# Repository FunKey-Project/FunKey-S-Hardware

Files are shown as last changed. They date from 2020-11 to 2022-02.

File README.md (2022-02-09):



## FunKey S Hardware
This repository contains all the hardware design and production files required to build the [FunKey-S retro-gaming console](https://www.funkey-project.com/) electronic PCBA using the [KiCAD ECAD tools](https://kicad.org/).

If you don't want to install these tools but still want to get an idea of what it looks like, you can check the [schematics](https://github.com/FunKey-Project/FunKey-S-Hardware/blob/master/PDF/FunKey%20Schematics.pdf) and the [layout](https://github.com/FunKey-Project/FunKey-S-Hardware/blob/master/PDF/FunKey%20PCB.pdf) in PDF format, the interactive [BOM](https://github.com/FunKey-Project/FunKey-S-Hardware/tree/master/BOM) is directly in HTML format, you can download it and display it in a browser.

The FunKey S is a small foldable retro-gaming console.

Its electronic parts consist in:
 - 1x main PCB (0.8 mm thickness) with components on both sides, the maximum component height above PCB on both sides is 1.5 mm. Current revision for this board is Revision E
 - 1x 1.54” IPS LCD TFT screen with SPI interface and using a custom flex cable
 - 1x 420 mAh 402540 LiPo battery

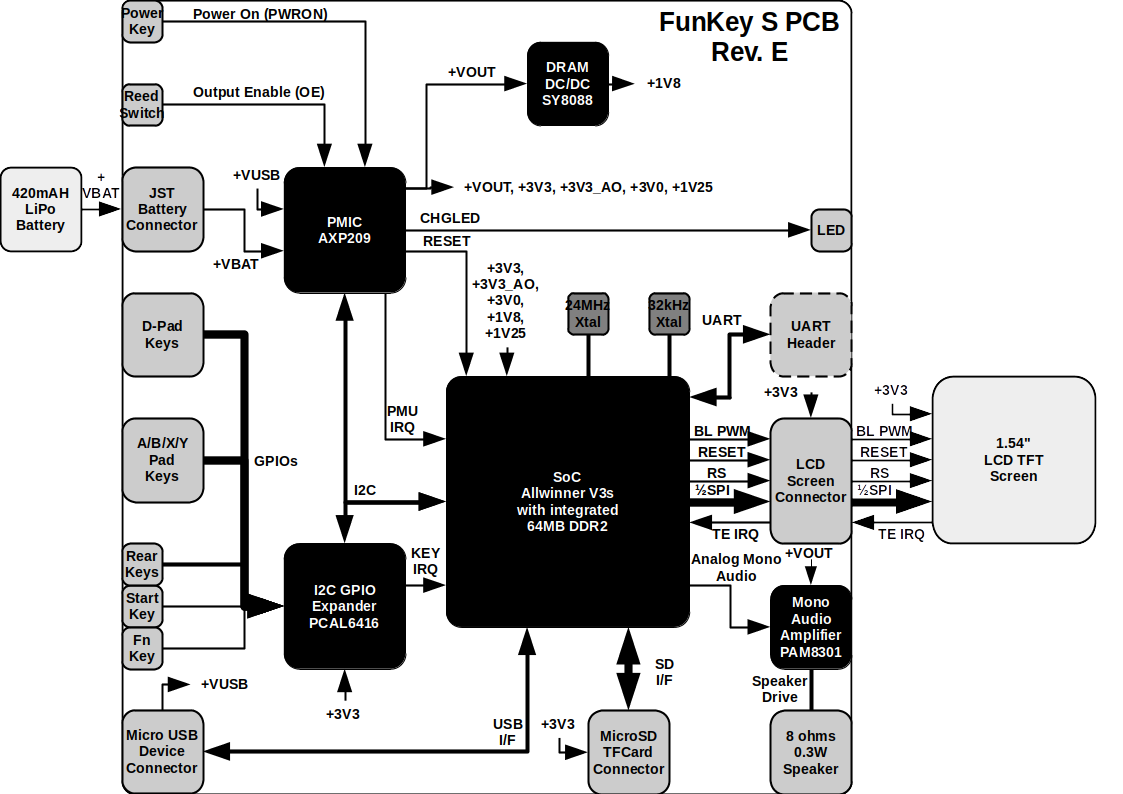
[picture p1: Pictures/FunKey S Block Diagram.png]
FunKey S Block Diagram


The FunKey S PCBA Rev. E contains the following main components:
 - 1x Allwinner V3s SoC with integrated 64MB DDR2 DRAM (LQFP128 package)
 - 1x X-Powers AXP209 companion PMIC chip to provide almost all required power supply rails (QFN48 package)
 - 1x Sylergy SY8088 Buck DC/DC SMPS chip to provide the DRAM power supply rail (SOT23-5 package)
 - 1x NXP PCAL6416 I2C GPIO expander to control all buttons and keypads (except Power Key) (QFN24 package)
 - 1x Diodes Inc. PAM8301 mono audio amplifier (TSOT26 package)
 - 1x 24 MHz main crystal
 - 1x 32.768 kHz RTC crystal
 - 1x Standex-Meder MK24 Reed switch for magnet proximity detection
 - 1x LED for charge indication
 - 1x 8 Ω 0.3 W built-in speaker
 - 1x Micro USB edge-mounted connector
 - 1x Micro SD (TF Card) Push/Push low-profile connector
 - 1x Hirose DF37 0.4 mm pitch miniature LCD connector
 - 1x JST 1 mm pitch battery connector
 - 1x 1.27 mm pitch debug UART header (not mounted)

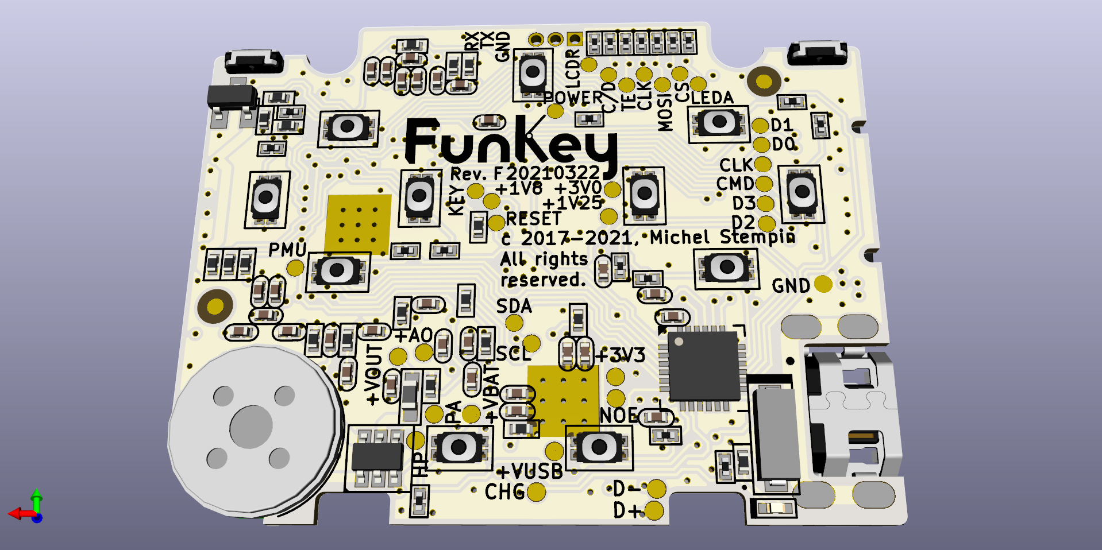
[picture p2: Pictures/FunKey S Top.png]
FunKey Top


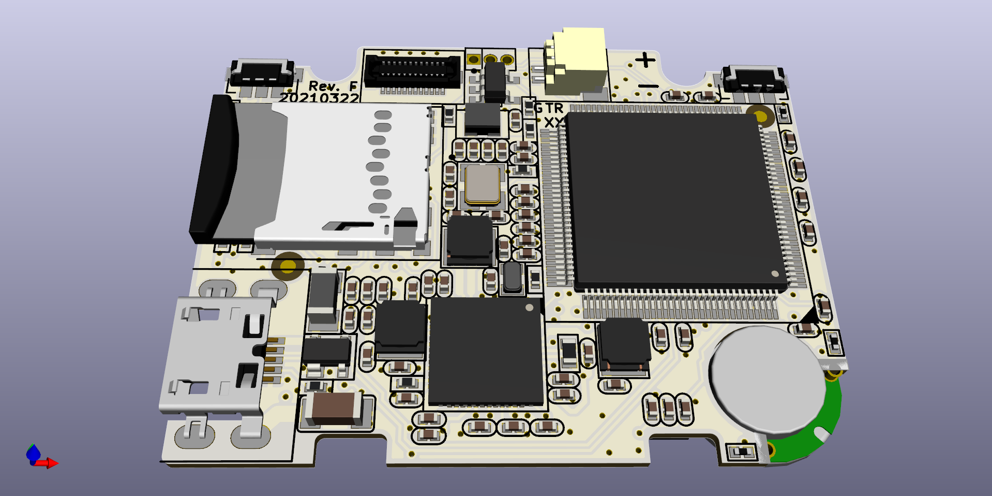
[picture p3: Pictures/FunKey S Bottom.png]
FunKey Bottom


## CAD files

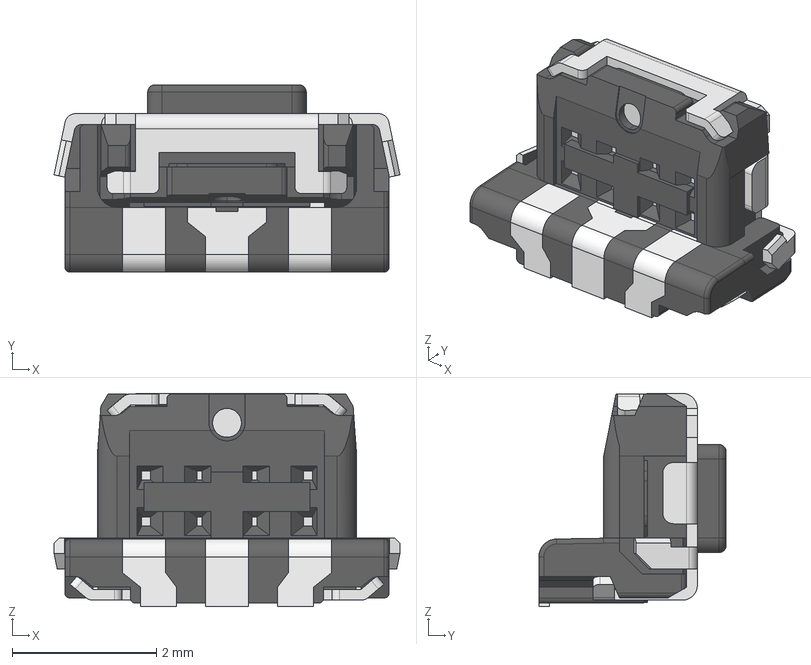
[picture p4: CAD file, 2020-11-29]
shapes3D/EVPAEBB2A.step
4.80 x 2.60 x 2.96 mm
EVPAEBB2A
EVPAEBB2A001
EVPAEBB2A002
EVPAEBB2A003
EVPAEBB2A004
EVPAEBB2A005
EVPAEBB2A006
EVPAEBB2A007
EVPAEBB2A008
EVPAEBB2A009
EVPAEBB2A010
EVPAEBB2A011
EVPAEBB2A012
EVPAEBB2A013

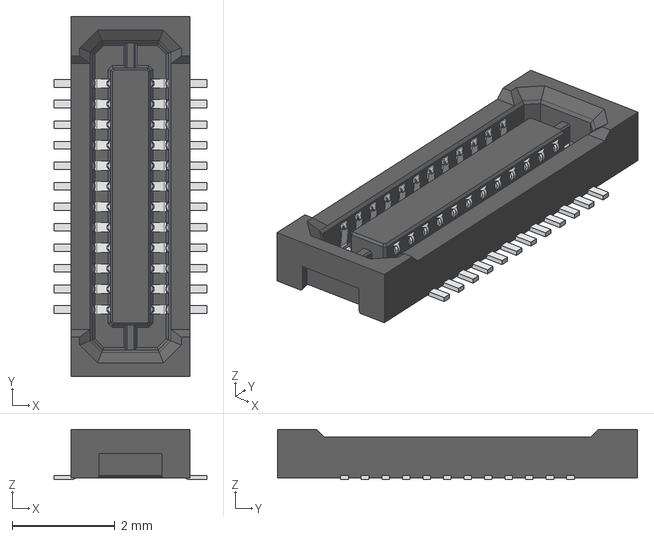
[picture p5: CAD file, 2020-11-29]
shapes3D/HIROSE_DF37NC-24DS-0.4V.step
2.98 x 7.02 x 0.98 mm

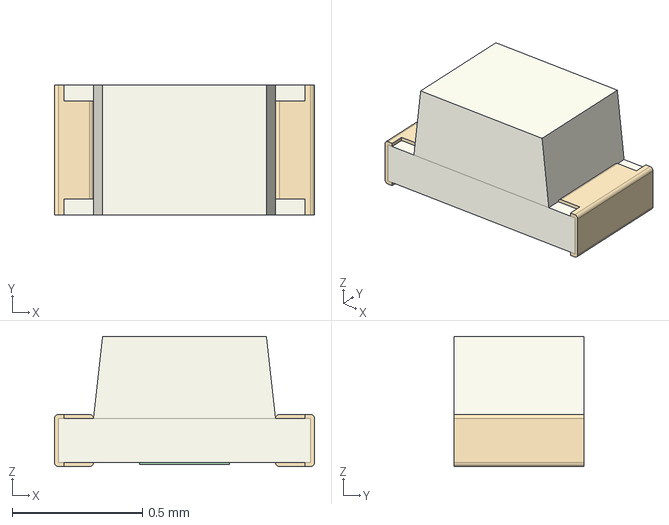
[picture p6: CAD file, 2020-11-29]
shapes3D/LED_0402_1005Metric.step
1.00 x 0.5 x 0.5 mm

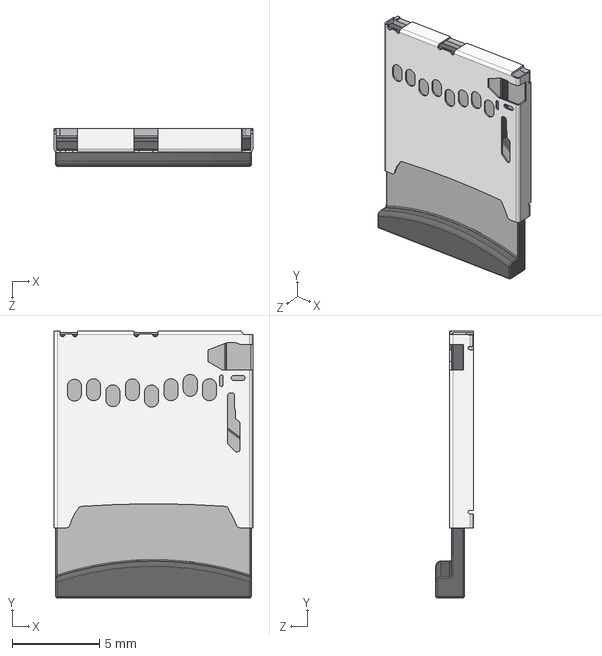
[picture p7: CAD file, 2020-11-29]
shapes3D/TF-110_with_Micro-SD.step
11.3 x 15.3 x 2.15 mm
CONNECTOR MICRO SD TF-110
MicroSD

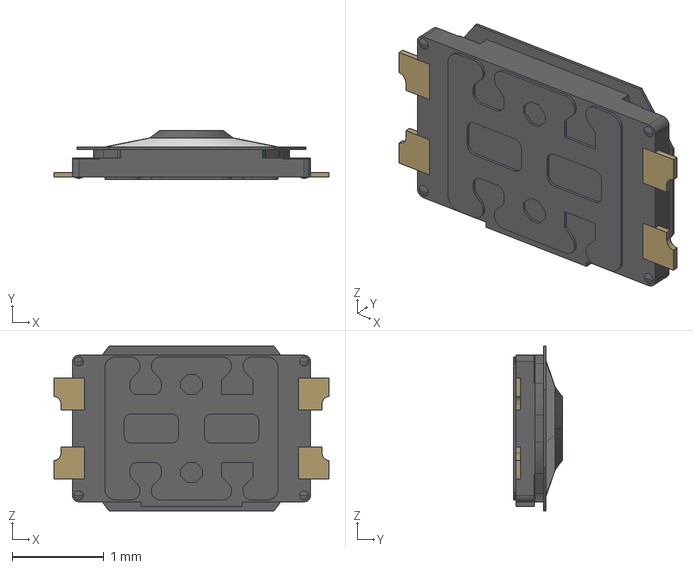
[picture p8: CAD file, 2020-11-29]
shapes3D/PANASONIC_EVPBB2A9B000.step
3.00 x 0.53 x 1.80 mm

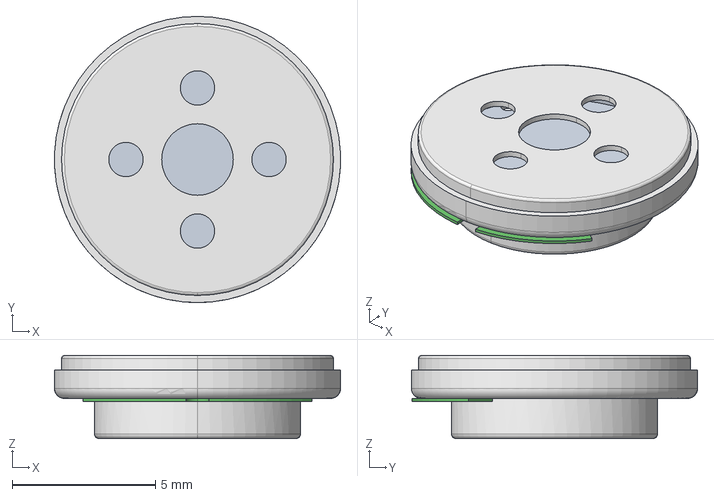
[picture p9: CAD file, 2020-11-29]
shapes3D/CUI_CDM-10008.step
9.99 x 10.0 x 2.90 mm

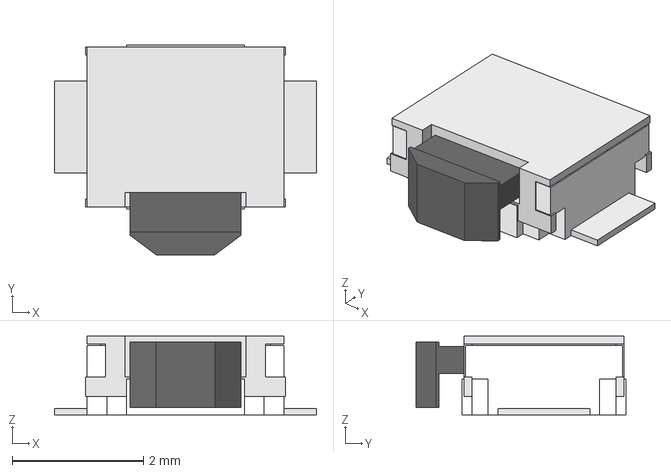
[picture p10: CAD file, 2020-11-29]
shapes3D/OMRON_B3U-3000P.step
4.00 x 3.20 x 1.20 mm

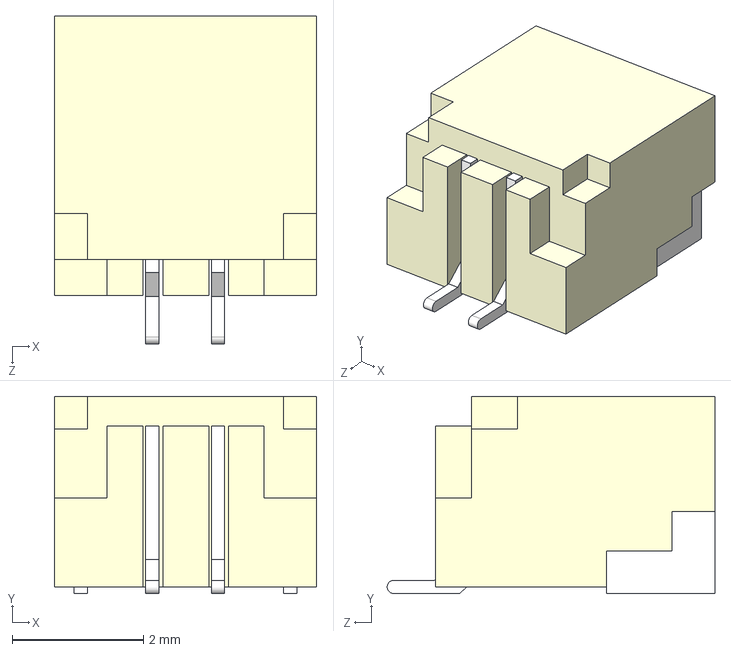
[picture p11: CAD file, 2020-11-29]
shapes3D/JST_SM02B-SRSS-TB.step
3.99 x 3.00 x 4.99 mm

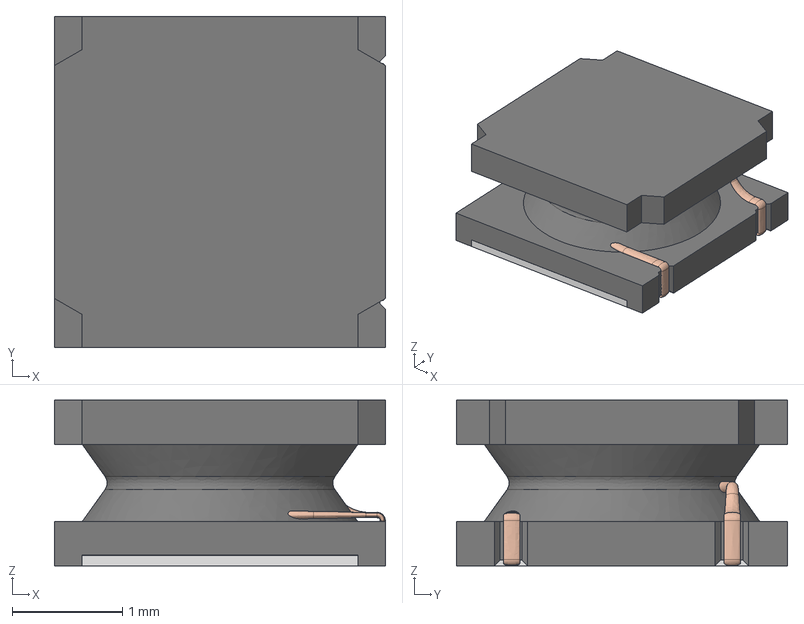
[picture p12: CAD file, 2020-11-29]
shapes3D/WE-LQS-3015.step
3.00 x 3.00 x 1.50 mm

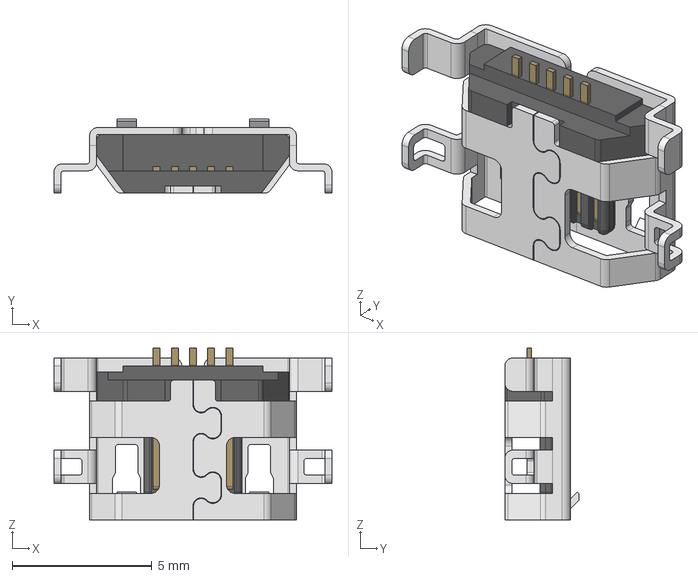
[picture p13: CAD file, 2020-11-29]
shapes3D/U02-BFD3111B0-009.step
9.95 x 2.66 x 6.15 mm

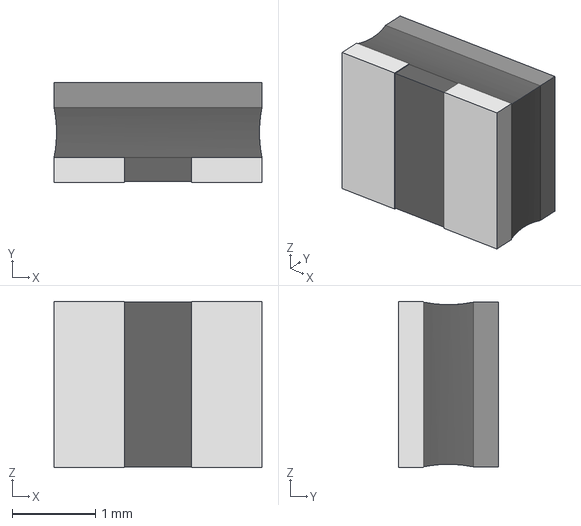
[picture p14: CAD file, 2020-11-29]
shapes3D/L1008.step
2.50 x 1.20 x 2.00 mm

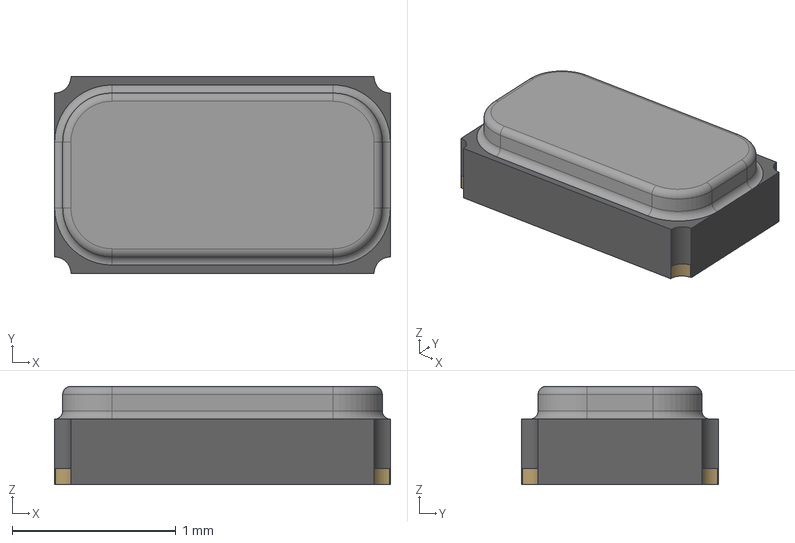
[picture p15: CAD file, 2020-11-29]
shapes3D/FC-12M.step
2.05 x 1.20 x 0.6 mm

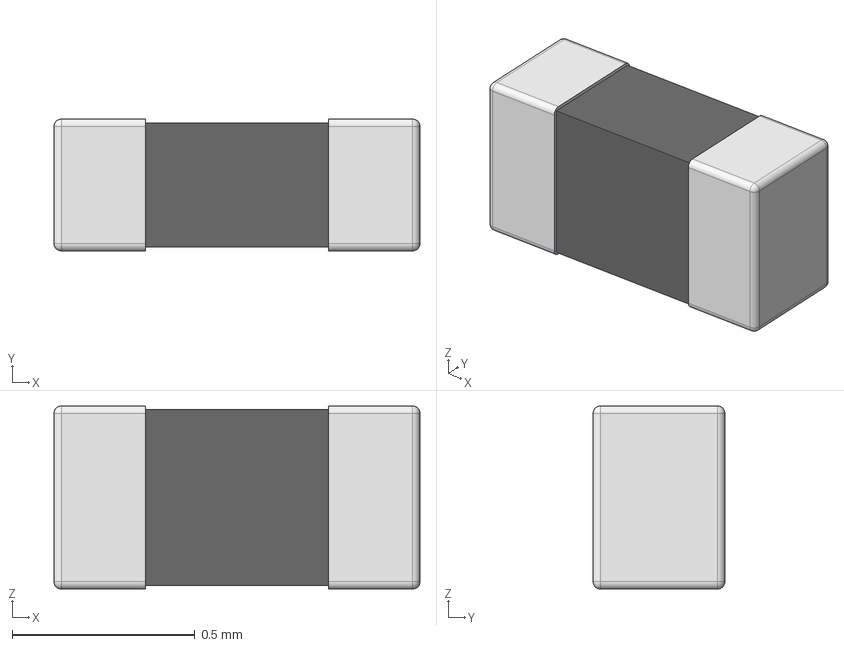
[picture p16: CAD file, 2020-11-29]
shapes3D/CG0402MLC.step
1.00 x 0.36 x 0.5 mm

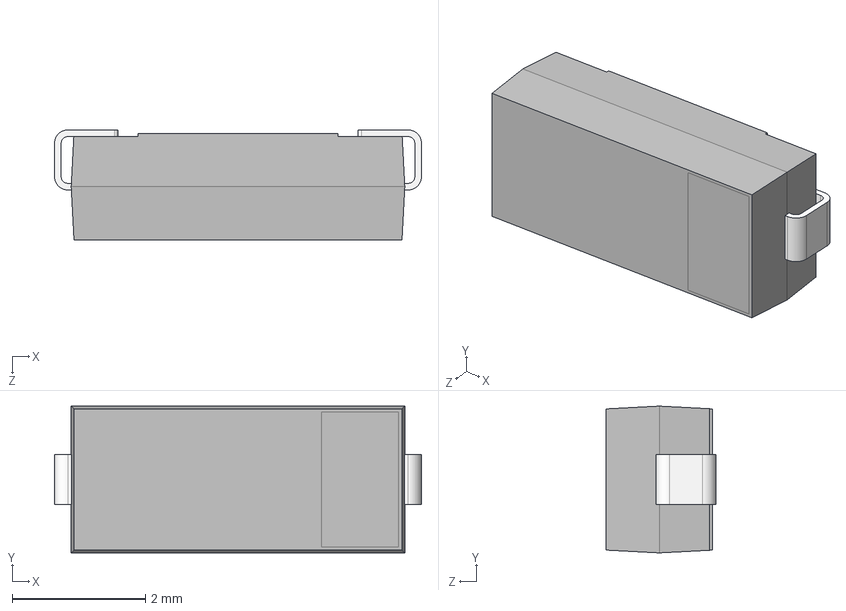
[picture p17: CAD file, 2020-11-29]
shapes3D/MEDER_MK24-A-3.step
5.50 x 2.20 x 1.65 mm

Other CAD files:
shapes3D/CRYSTAL-3225.step

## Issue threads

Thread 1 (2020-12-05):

What LCD is this? and the Driver Chip?

Helder1981, 2020-12-05:
This looks like a custom made LCD or a standard LCD with custom Flex on it. Can you tell us what the original LCD was or the driver IC it uses so other LCDs can be used.

Thanks.

Michel-FK, 2021-02-20:
The original screen we used is a SAEF SF-TC154B-8377A-N which used to be available on Alibaba, but this is no longer the case.

You can find its datasheet attached.

It uses an ST7789V integrated driver IC.

[ALIBABA_SAEF_SF-TC154B-8377A-N_annote.pdf](https://github.com/FunKey-Project/FunKey-S-Hardware/files/6016271/ALIBABA_SAEF_SF-TC154B-8377A-N_annote.pdf)

Our current screen is no longer manufactured by SAEF, but our changes to the orignal model are:

- change the flex shape and dimensions
- add the TE (Tearing Effect) signal from the driver IC on the connector (pin 9)

Here is our current screen specs:
https://github.com/FunKey-Project/FunKey-S-Hardware/blob/master/Datasheets/DISPLAY%20-%20SF-TC154B-8737A-N%20-%20CUSTOM%20FLEX%20-%200.3.PDF

Closed 2021-02-20.

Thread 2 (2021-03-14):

PMIC default voltages

wolfallein, 2021-03-14:
Hi,

very nice project and very well documented! Congrats!

I have a question regarding the default voltage on the AXP209. I was reading the datasheet but it is not very clear how the voltage is set when the system starts, before u-boot, or kernel takes control.

For the LDO1, and DC3 there are some set pins that in the funkey schematic sets them to 3.3V.
The Vdram is fixed to 1.8V.

LDO2 can vary from 1.8V-3.3V, but in the schematic it is 3.0V.
DC3 can vary from 0.7-3.5V, but in the schematic it is 1.25V (Vcore).

So, how the voltage is set before the CPU wakes?

BR

Michel-FK, 2021-03-15:
Hi,

Just a small precision: Vcore is DC2, not DC3.

Yes, the AXP209 datasheet is not clear at all regarding the default voltages, and has some [other mistakes](http://www.chip-community.org/index.php/AXP209) too.

In the [Allwinner V3s reference design](https://github.com/Squonk42/V3s_Documentation/blob/master/V3S_CDR_STD_V1_0_20150514.pdf), the AXP203 is used with the following configuration

- LDO1: 3.3V Always On (RTC/GSensor)
- LDO2 : 3.0V(AVcc/pll)
- LDO3: 0.7~3.V (Camera AVDD)
- LDO4: 1.25~3.3V (Camera DVDD)
- DC2: 1.25V (CPU/SYS/EPHY)
- DC3: 3.3V (USB/NOR/TF/FLASH/LED/VCC-IO/LCD)

As X-Powers is an Allwinner sister company specialized in power chips for the Allwinner SoC, they are tailor-made for these chips, and as the AXP209 was sold on Aliexpress as a bundle with the V3s, we figured out that it would default to the right settings regarding the adjustable output voltages.

It is indeed the case, and as in the reference design, the default voltages for LDO2 is 3.0V, and DC2 is 1.25V, despite the lack of information in the datasheet (default values are XXXX!).

So, there is no software adjustment required at all during the whole boot process.

Upon startup, the voltages are thus:

- LDO1: 3.3V Always On 30mA (Vcc_rtc)
- LDO2 : 3.0V 200mA (AVCC/Vcc_pll)
- LDO3: N/U
- LDO4: N/U
- DC2: 1.25V 1.6A (Vcpu/Vsys/Vdd_phy)
- DC3: 3.3V 1.2A (Vcc_io/Vcc_ephy/Vcc_mcsi/Vusb/Vcc_io)
- External SY8088AAC DC/DC for 1.8V 1.0A (Vdram)

wolfallein, 2021-03-15:
Thanks a lot for the information.

This was driving me crazy. I also found small mistakes everywhere in their datasheets, seems like they never got a final version.

They always say:
`
"As for more details, please refer to “Default Configuration Instruction".
`

But this section simply doesn't exist.

I was particularly worried about the default voltages because XX means that it can be any value, and this is definitely not good for power regulators that drive SOC's.

I found some differences in their chips, they are not 100% pin-compatible:

* AXP203 -> PIN 27=LDO1SET, PIN15=LX3, PIN16=PGND3
* AXP202 -> PIN 27=PWREN, PIN15=LX3, PIN16=PGND3
* AXP209 -> PIN 27=LDO1SET, PIN15=PGND3, PIN16=LX3

Maybe there are little differences in their registers (like max voltages, timing...), but I didn't check.

I could only see the bundle with the AXP203 at Aliexpress now, so something to consider when buying it ...

Just some little notes regarding the schematic:

1. I noticed there is missing a diode for protection in parallel with the battery connector. I guess you assumed the battery already has such protection, but this is not always the case. If the user replaces the battery with another model that doesn't have the protection and connects with inverted polarity, it can be dangerous, and a single diode could help to increase safety.

2. I see the reed switch is connected to N_OE pin, and from what I could see, it is a power cut. A hardware power cut could generate some corrupted data if the system is mounted as r/w. Since the OS is very limited the chances are low, but maybe you get a bad write in 1/100 (just guessing), maybe with a few of them the system won't be able to boot properly. The axp20x series has a very good mainline kernel support and the power button can send a soft power off or sleep input to the system. The GPIO pins can also behave as input to the system, but I couldn't find that N_OE can be input, although it can be configured to change IRQ state. Maybe I'm missing something, but wouldn't be better to connect the reed switch to PWRON, or one of the GPIO's to get a soft power off instead of using N_OE?

Again, I wanted to thank you for all the information and the detailed documentation of the system, very good work here!

In almost all DIY boards in the market, they claim open source, open hardware but you never get everything they promise.

All the best

Closed 2021-03-15.

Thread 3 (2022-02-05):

hiya -  is this project actually open source?

ladyada, 2022-02-05:
hi there, on the kickstarter page and hackaday page (https://hackaday.io/project/164934/logs) describing this product is the text

"Since its [origins](https://www.funkey-project.com/), the FunKey S has proudly been Open Hardware & Open Source."

with the open source hardware logo and OSI logo:

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

which is awesome! the open source hardware association, whose 'gear' logo is used on that page
https://www.oshwa.org/open-source-hardware-logo/
says
"This logo may be used if your hardware complies with the [Open Source Hardware Definition](https://www.oshwa.org/definition/)."
The definition at https://www.oshwa.org/definition/ specifies that you cannot have 'non commercial' as a restriction on the license.

This repository has a "Non Commercial" license tag.
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

please clarify:

- if this is open hardware and if so, please update the license so it matches the requirements of using the open hardware logo and description.
- or if it not open hardware, you cannot use the logo and must update the hackaday, kickstarter page, etc.

thank you :)

ladyada, 2022-02-09:
hiya @squonk42 @Michel-FK @Vincent-FK please look at this issue and reply!

ladyada, 2022-02-09:
also found on the wiki, another place that is not correct:

https://wiki.funkey-project.com/wiki/FunKey_Wiki_Knowledge_Center#What_is_the_FunKey_S?

```
Where can I find FunKey S device schematics and 3D files?

The FunKey Team has FunKey S schematics, STL files, and a project STEP file for the device's shell components available on [Grabcad](https://grabcad.com/library/funkey-s-1). Schematics for the device's electrical components are available on the FunKey Team's [GitHub page](https://github.com/FunKey-Project/FunKey-S-Hardware). As the device's hardware is open source, users are free to download, modify, and redistribute the listed files.
```

Vincent-FK, 2022-02-09:
Hi @ladyada,

Since it's our first product I must admit we're still tiptoeing around all the legal details so thanks a lot for your input, it's been corrected.

Oh and btw, it goes without saying but still: thanks for Adafruit! Without it Keymu would never have been prototyped, which by extension means the FunKey S would not be there either.

ladyada, 2022-02-09:
thats wonderful - thank you so much for updating the license. im really enjoying my funkey now EVEN MORE SO! :)

Closed 2022-02-09.

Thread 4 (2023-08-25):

Design issues with axp209 schematic

FantasyGmm, 2023-08-25:
The chip documentation states that the 23 Pin BIAS should be connected to a 200K 1% resistor, but in the schematic diagram, the R22 200K 1% resistor is connected to the 21 Pin APS pin,Is this a schematic error or a document error? In the AXP203 design, they all connected the 23 Pin BIAS series resistor to GND instead of grounding the 1uF capacitor

Closed 2023-08-26.

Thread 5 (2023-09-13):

Did you ever consider a hackable retro portable audio player / mp3 player (fork)?

sandreas, 2023-09-13:
Hey there,

I stumbled over this project and open hardware design while searching for a small handheld audio player that is NOT Android based (best case: hackable) and small enough to carry around. Basically, I'm still using my iPods (more specific: iPod Nano 7g with touch screen), because I did not find any alternative that can both play most modern codecs while also having good battery life yet.

So since you share ALL of your designs and hard work publicly, did you ever think of creating such a small audio player?

I think that you already got the most of the work done with the `Funkey S`... the only things I would consider is a non-foldable design with touchscreen and audio jack supporting [TRRS with OMTP](https://en.wikipedia.org/wiki/Phone_connector_(audio)#TRRS) for headphone remote controls (vol+, vol-, play/pause toggle).

If you wanna go all in, you could add some audiophile stuff like 4.4mm BAL 260mW @32-ohm output or Bluetooth 5 LDAC, AptX HD, SBC, AAC licensing - maybe even USB DAC Support

For the first prototype I would like to suggest a device similar to the [Fiio M6](https://www.fiio.com/m6), which is no longer available but was pretty successful. I own one of these and hardware wise it is by far the best audio player I ever had - only problem is the Software. Android 7 which is slow, long boot times and outdated app support.

A dedicated fast audio player with an app also supporting audio books would make a great buy in my opinion...

What do you think?

Closed 2025-02-08.

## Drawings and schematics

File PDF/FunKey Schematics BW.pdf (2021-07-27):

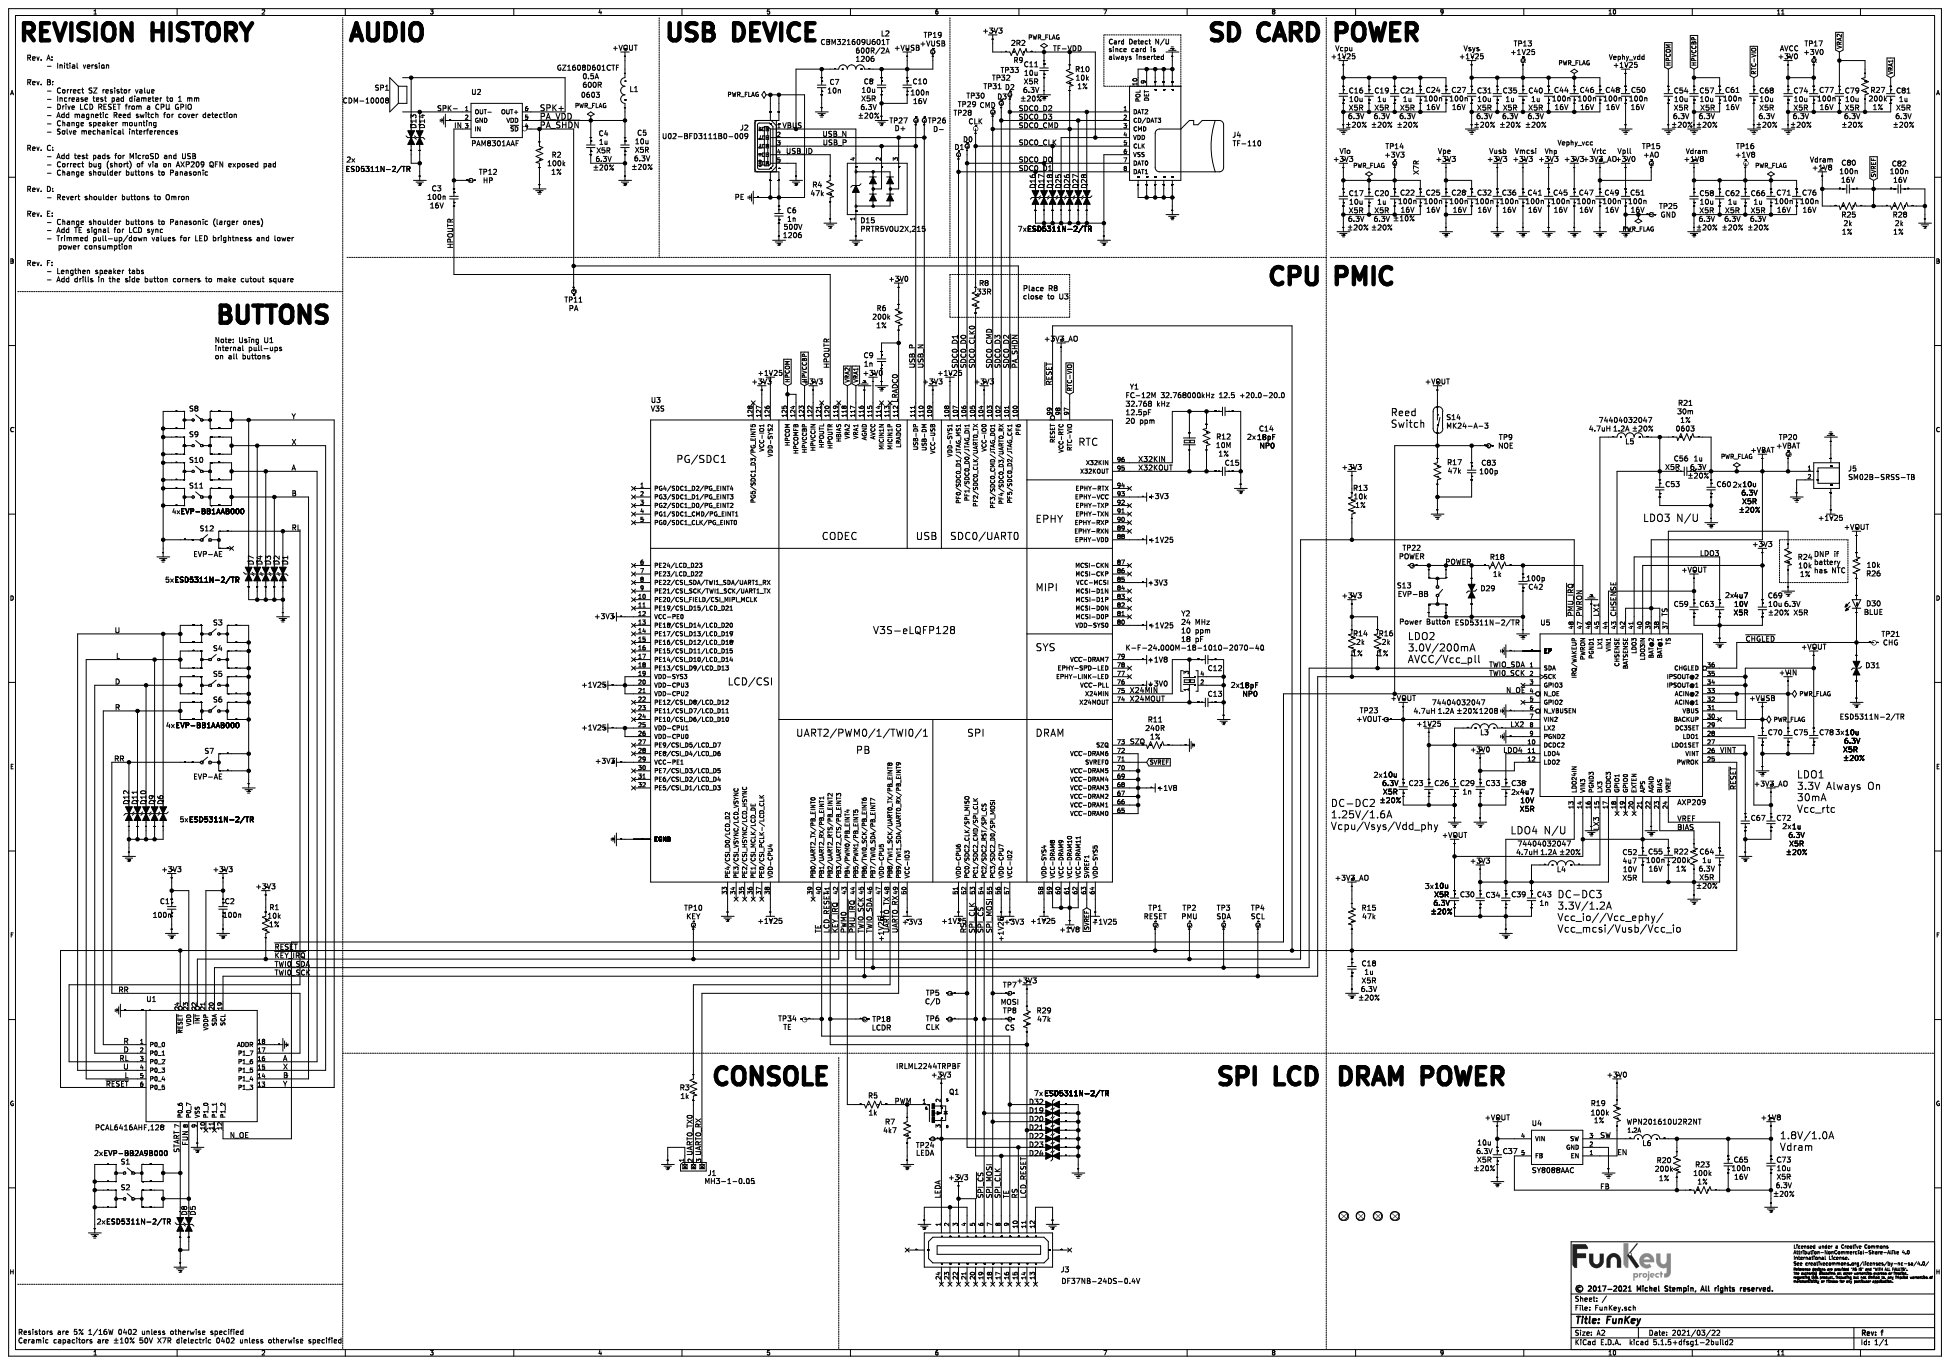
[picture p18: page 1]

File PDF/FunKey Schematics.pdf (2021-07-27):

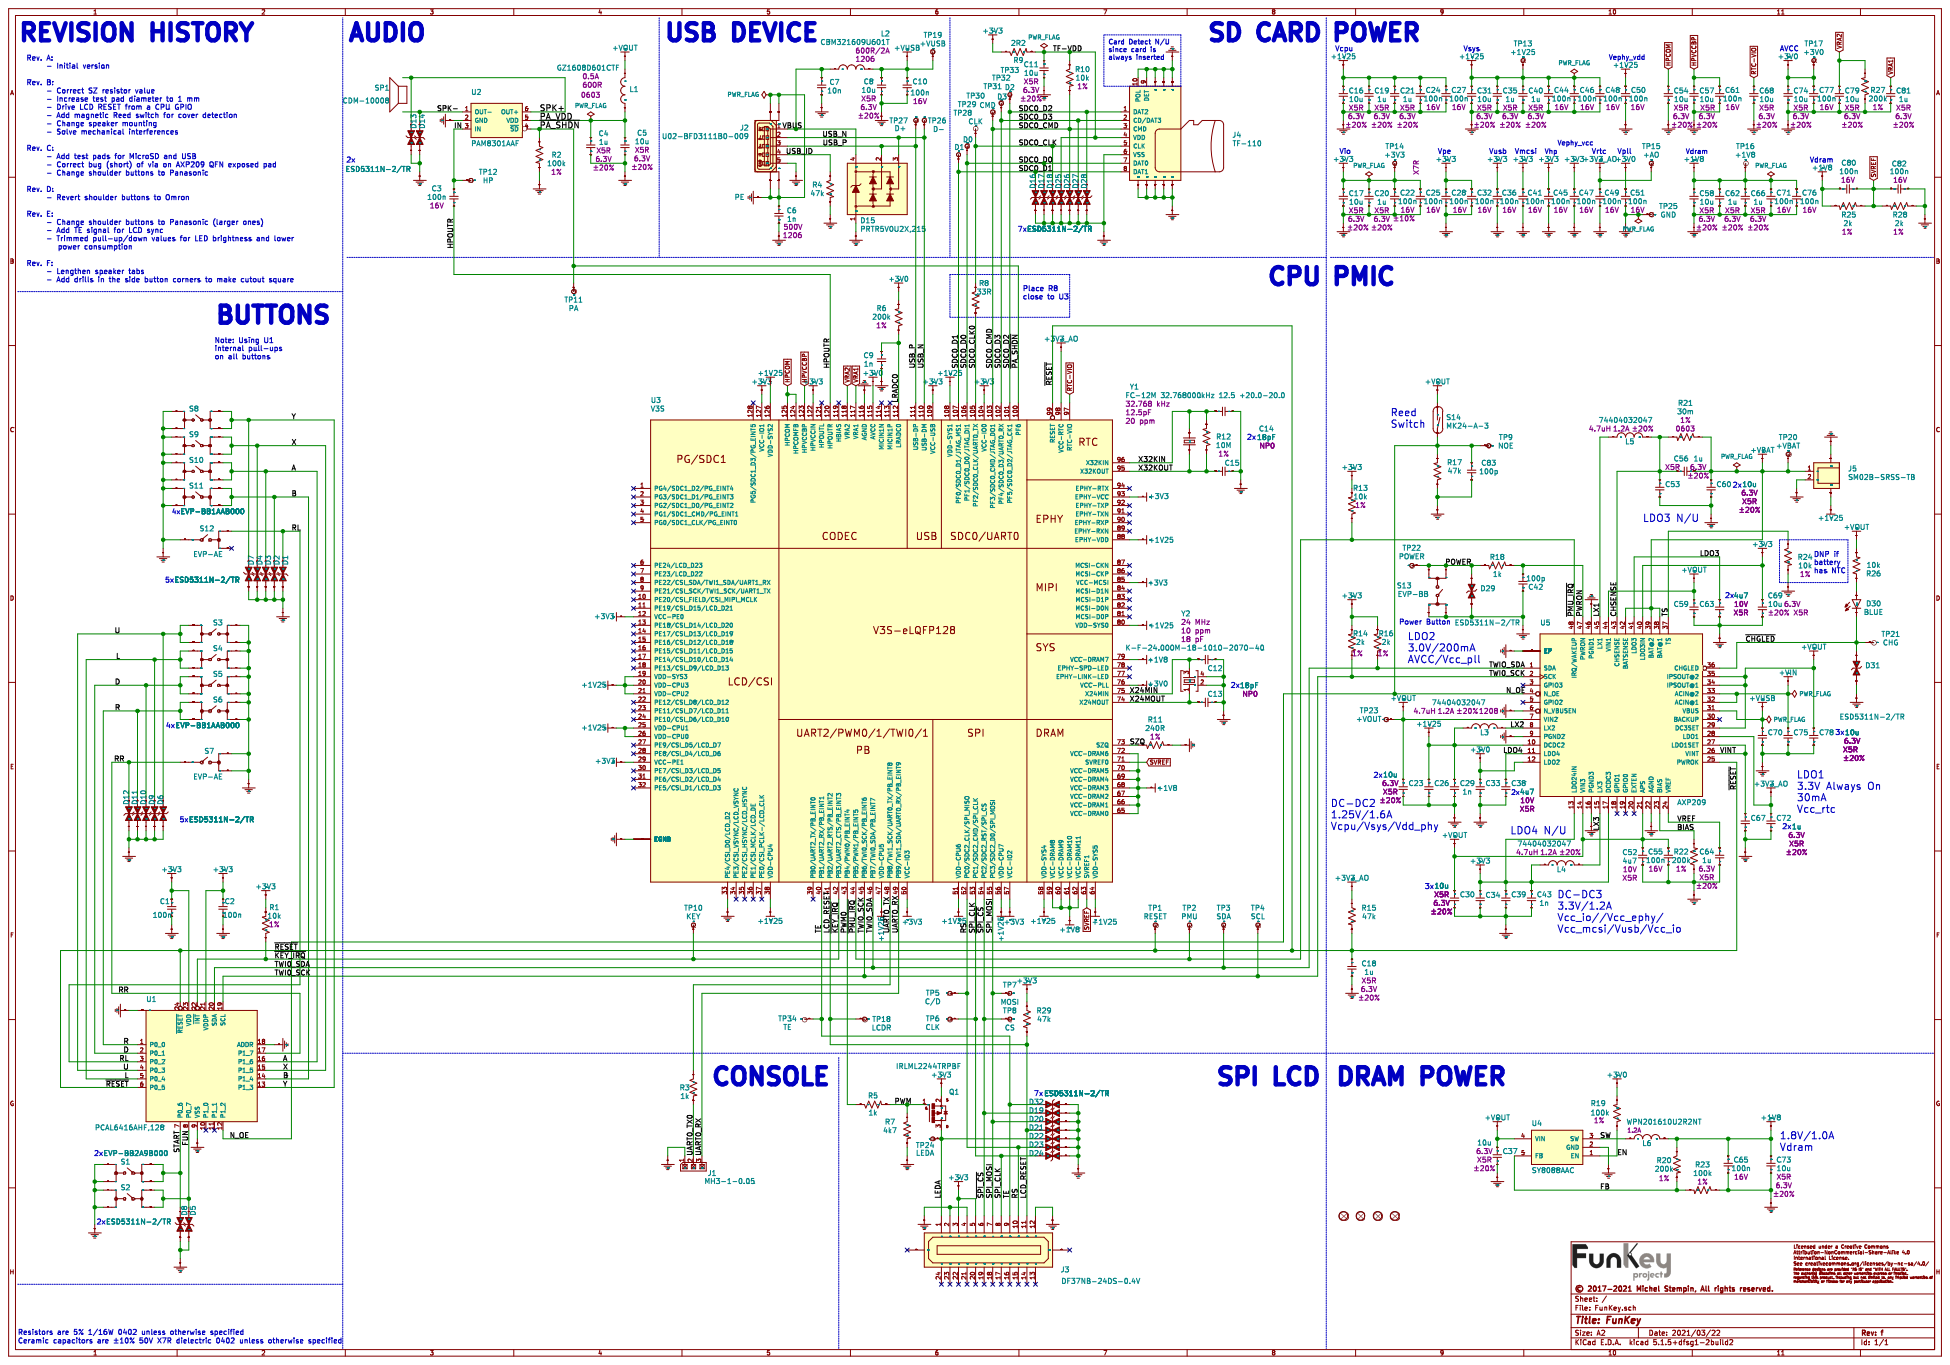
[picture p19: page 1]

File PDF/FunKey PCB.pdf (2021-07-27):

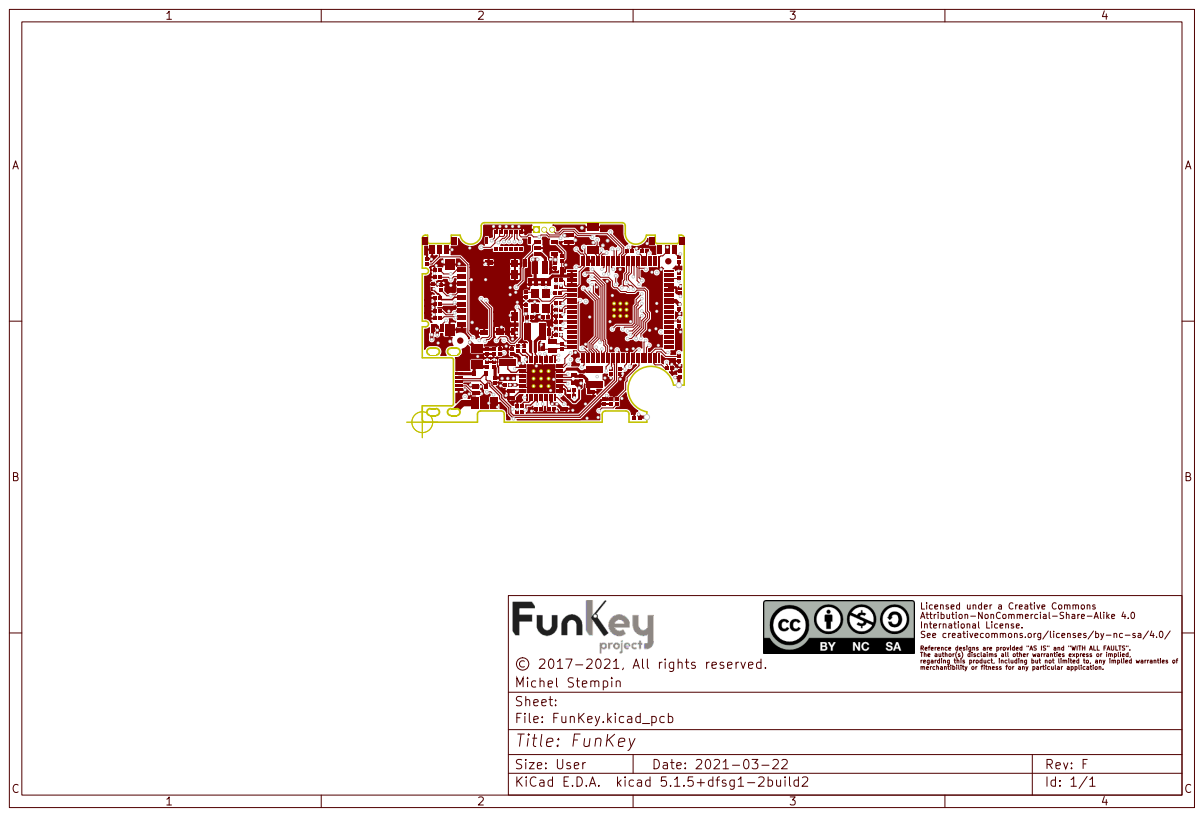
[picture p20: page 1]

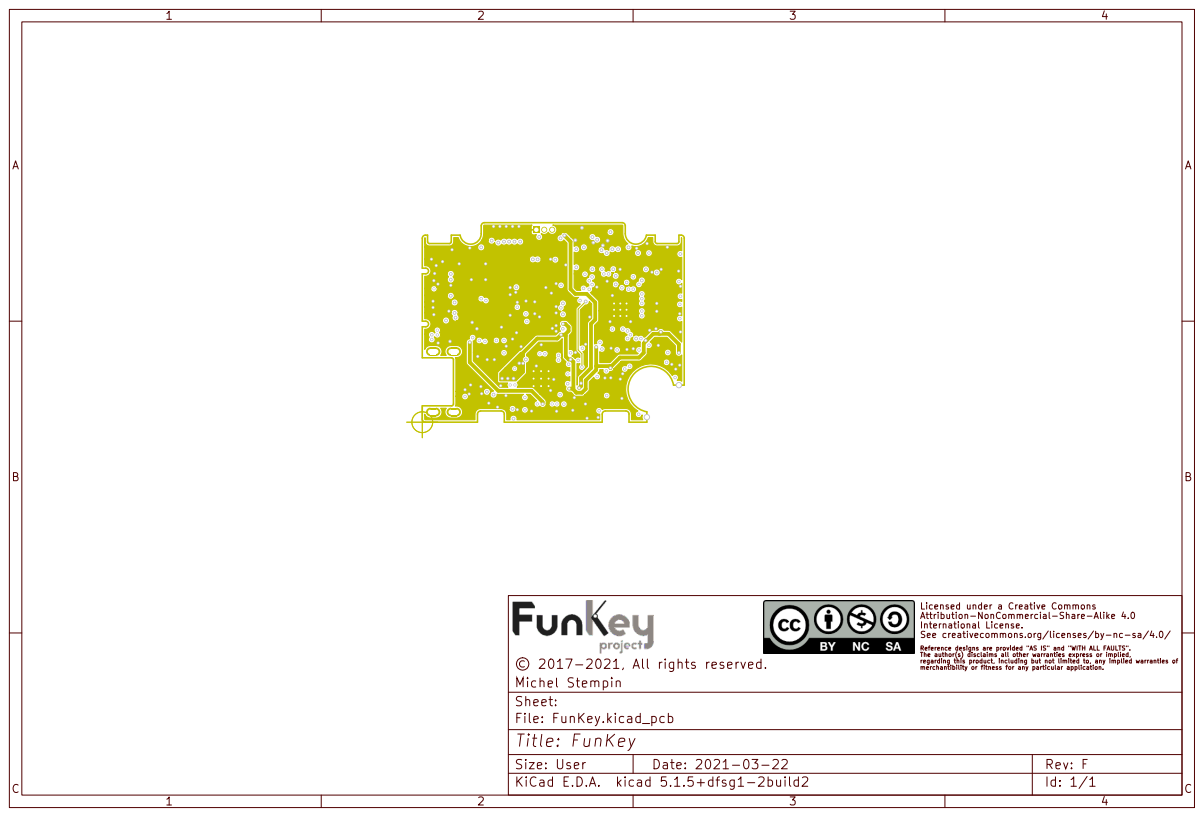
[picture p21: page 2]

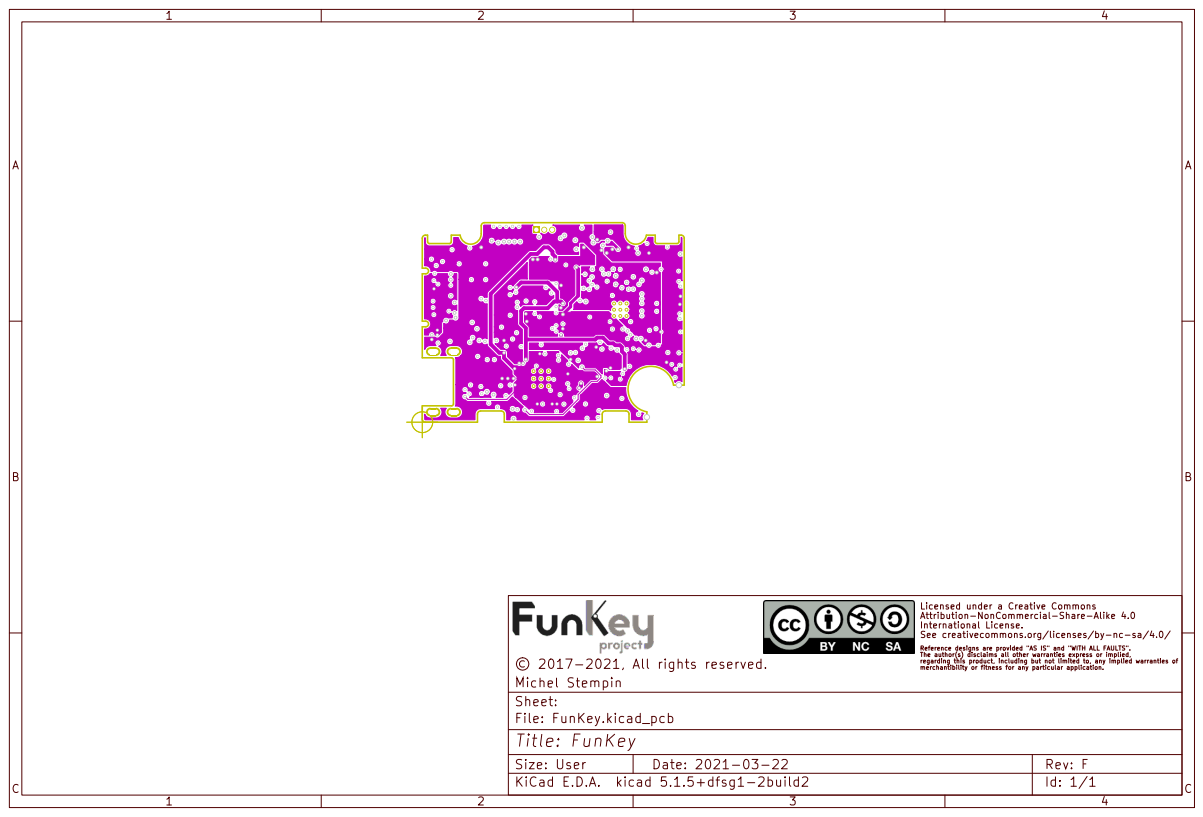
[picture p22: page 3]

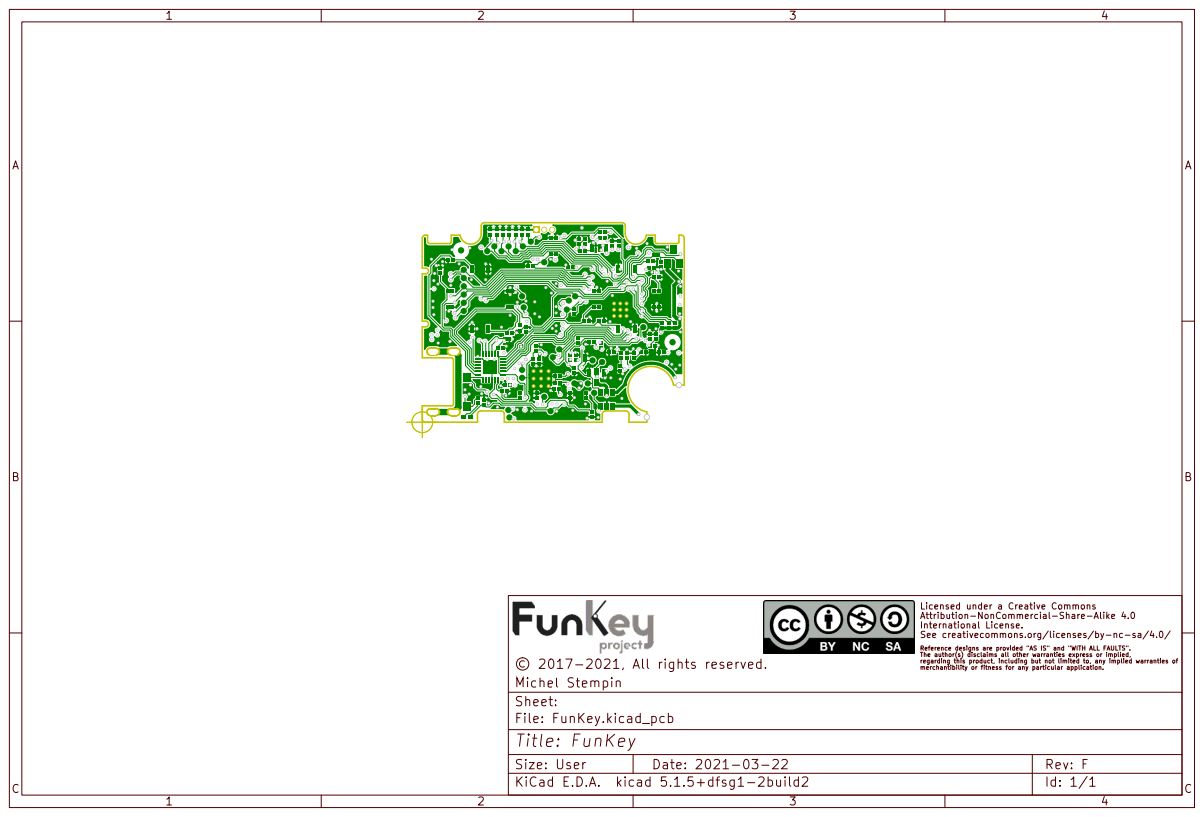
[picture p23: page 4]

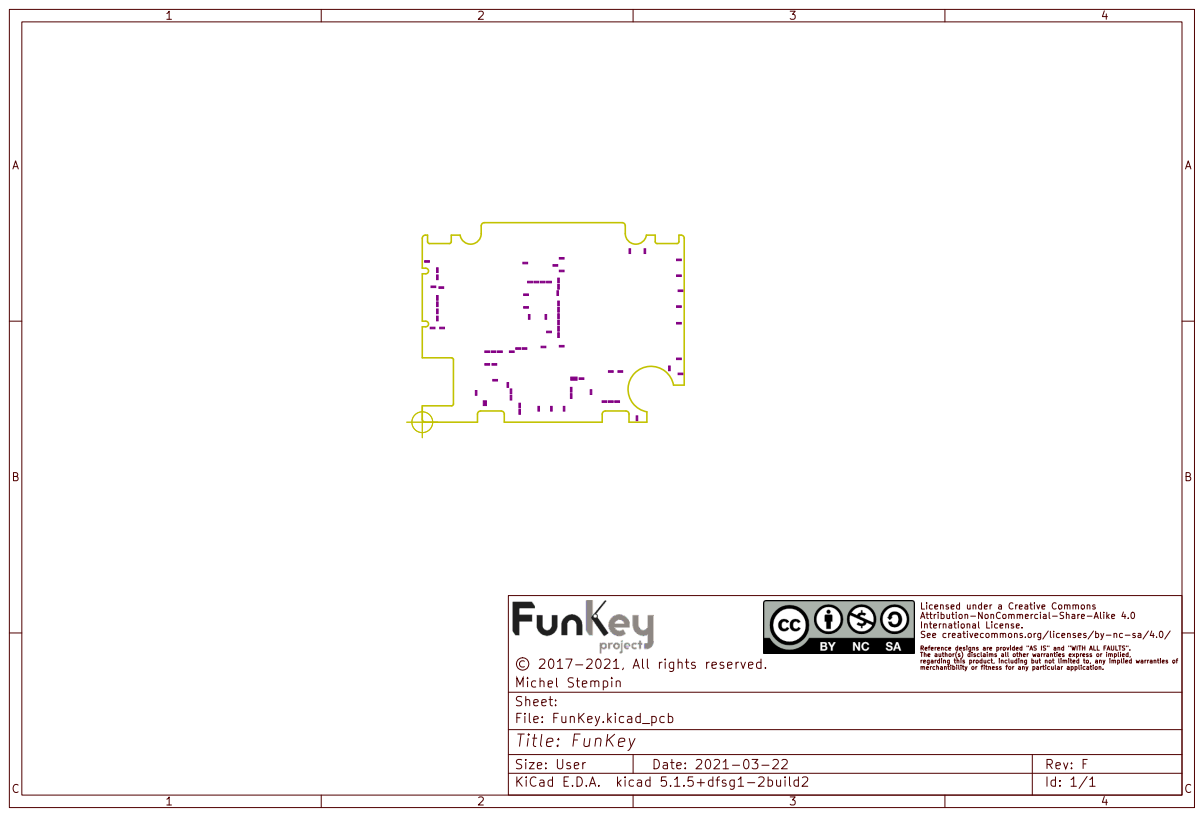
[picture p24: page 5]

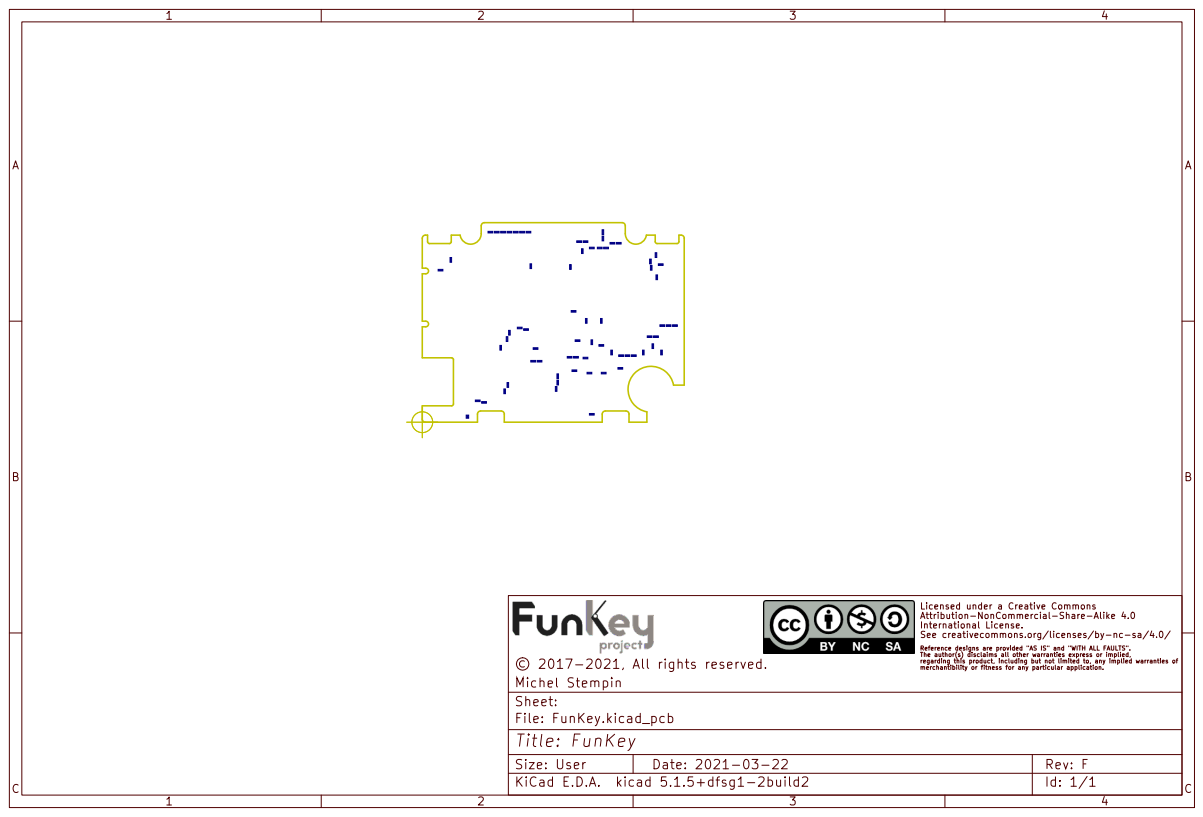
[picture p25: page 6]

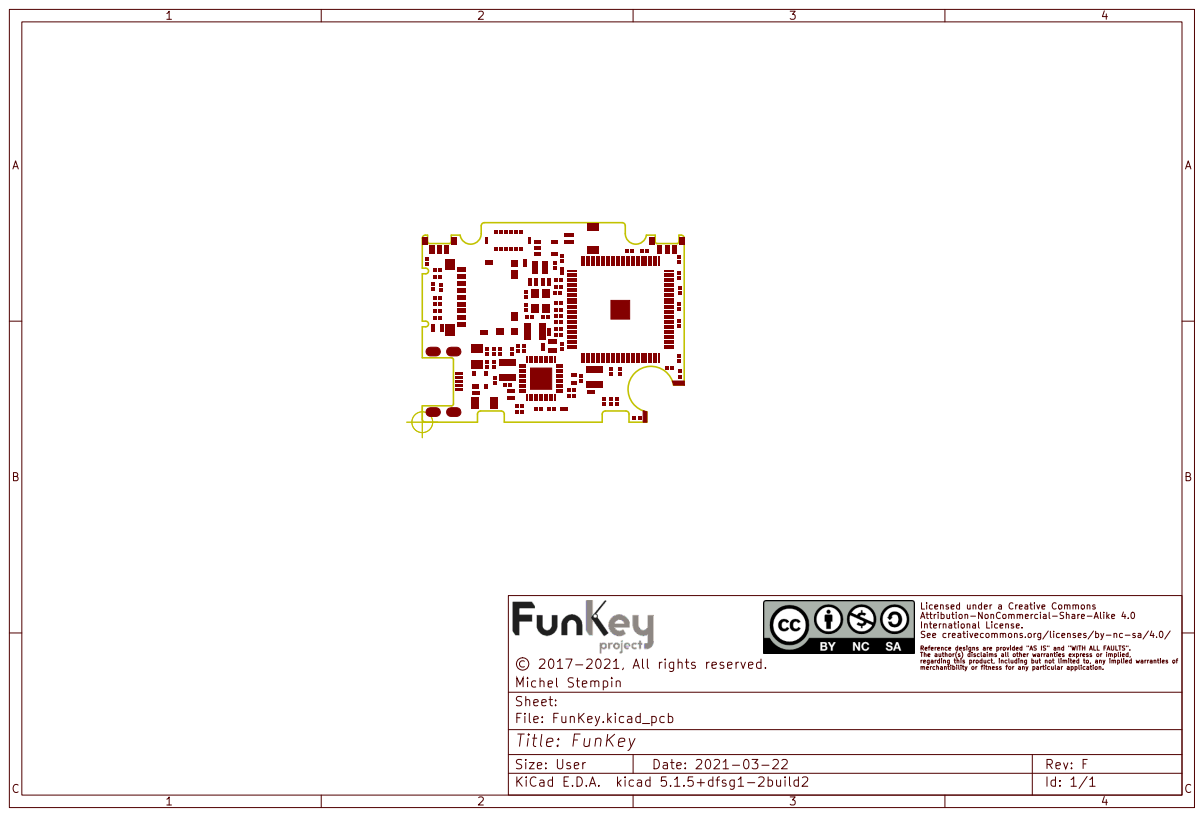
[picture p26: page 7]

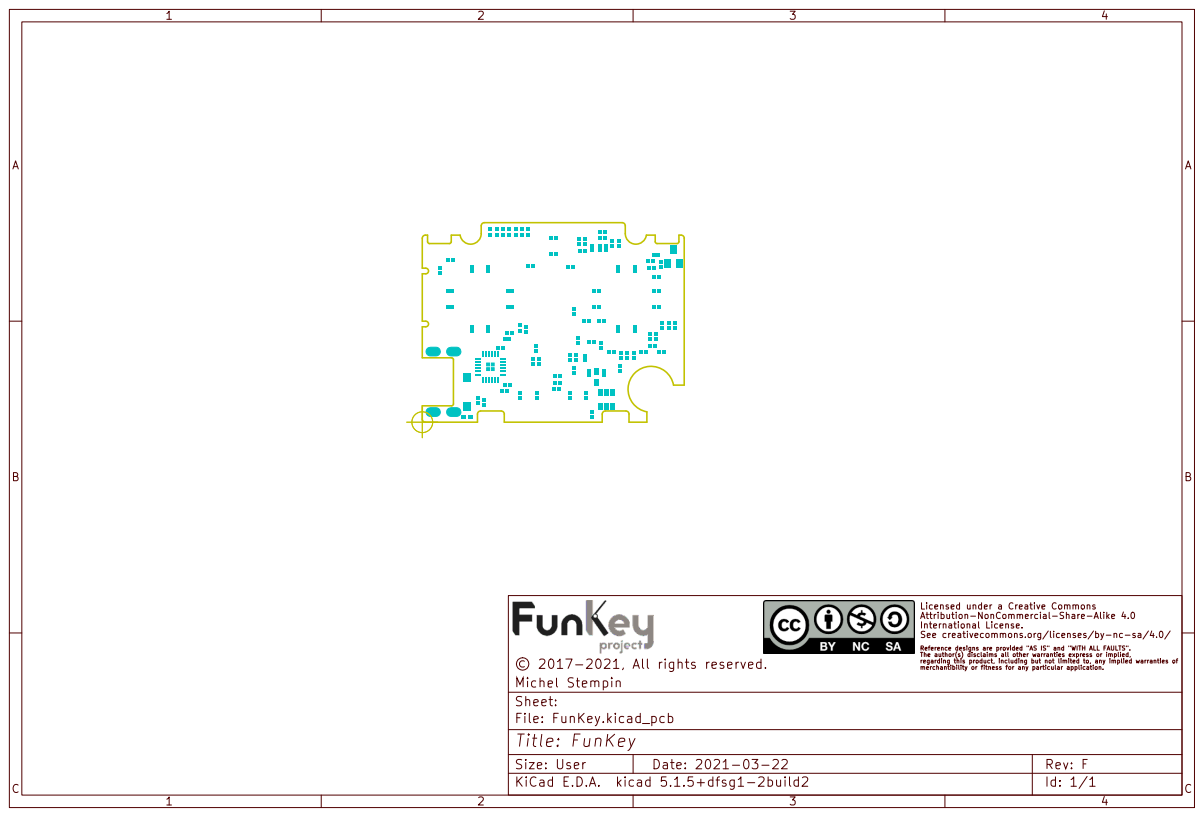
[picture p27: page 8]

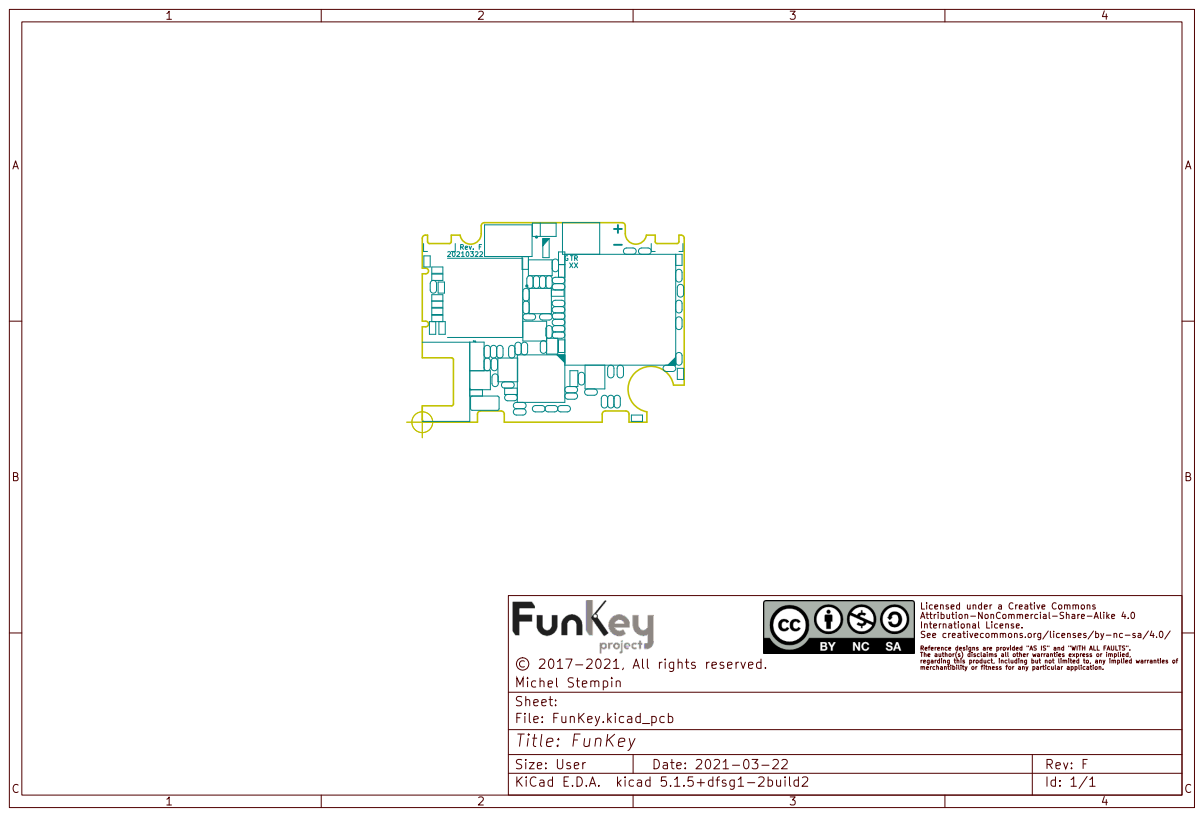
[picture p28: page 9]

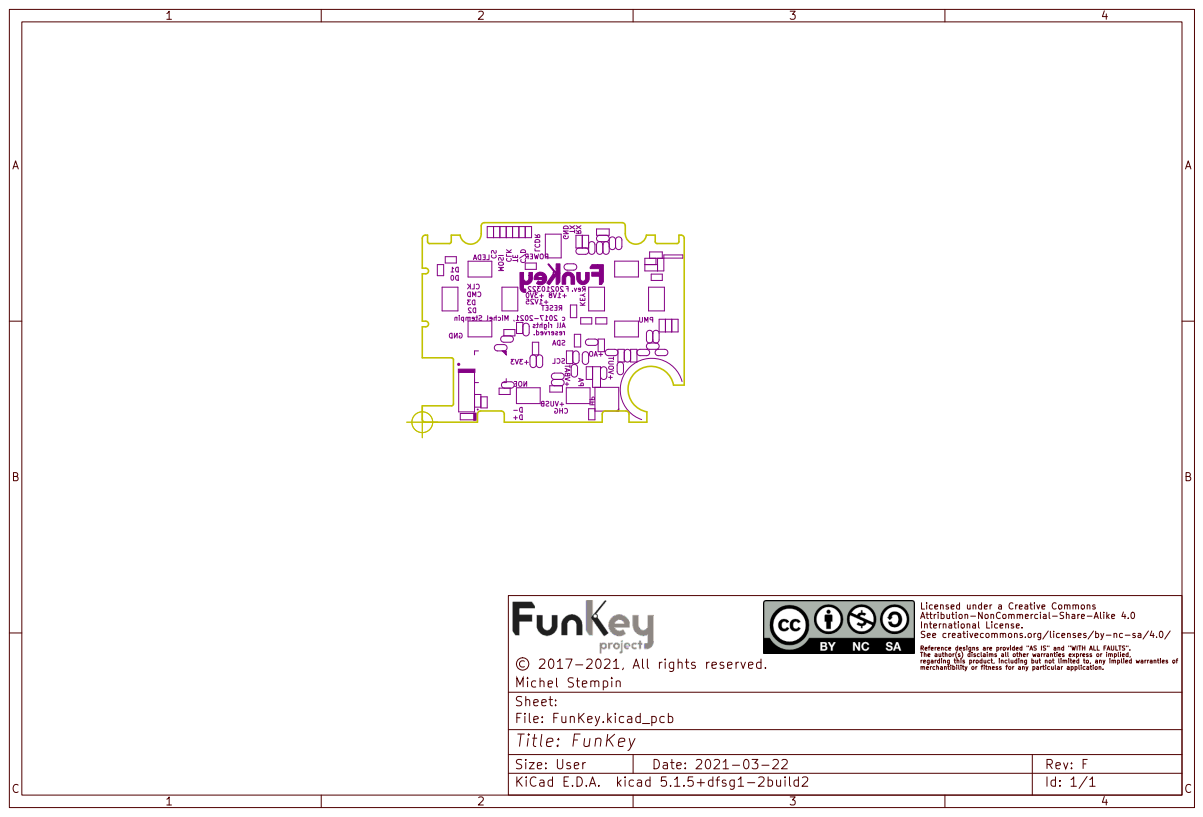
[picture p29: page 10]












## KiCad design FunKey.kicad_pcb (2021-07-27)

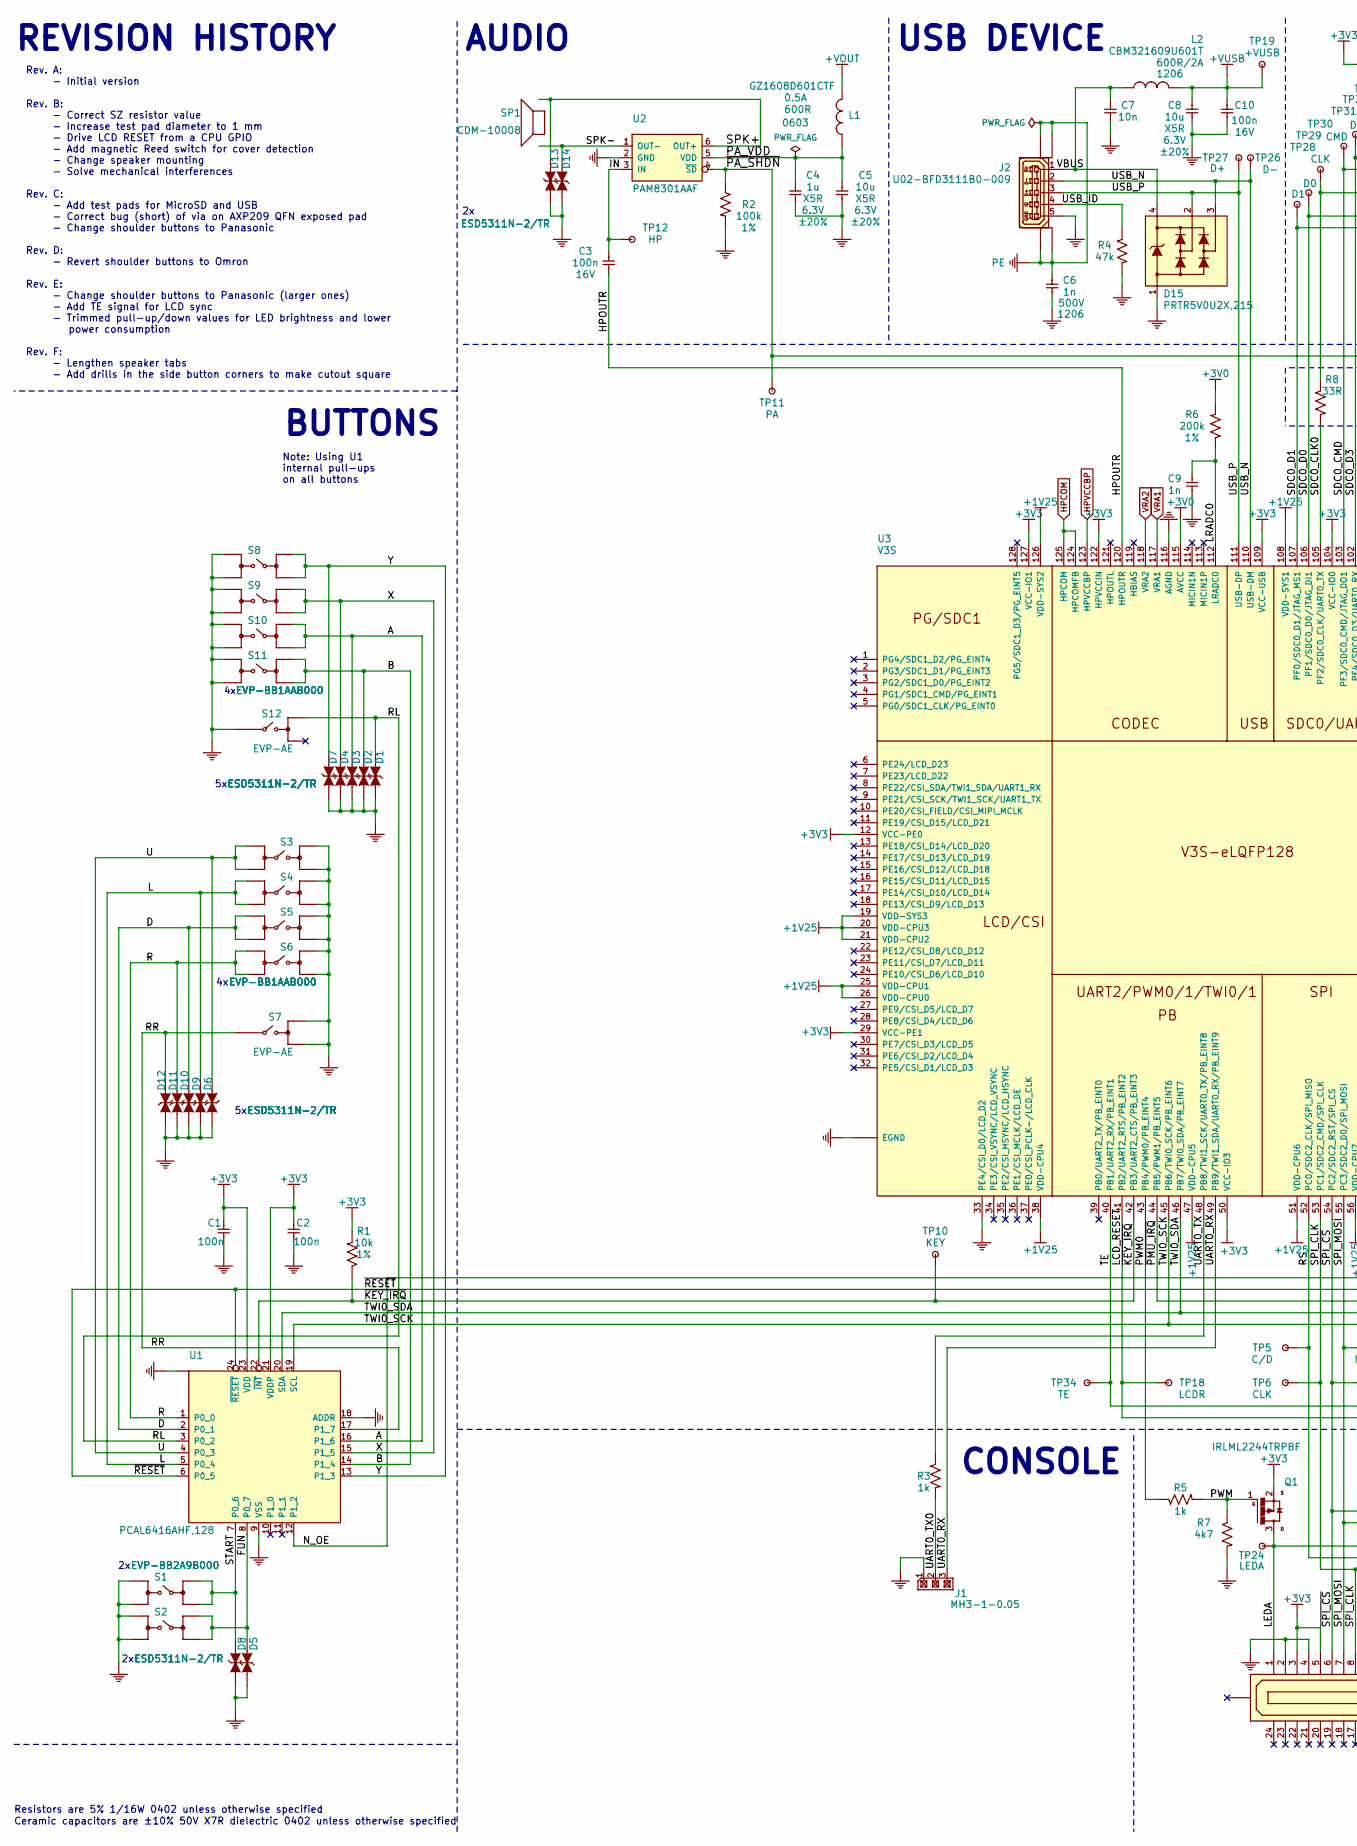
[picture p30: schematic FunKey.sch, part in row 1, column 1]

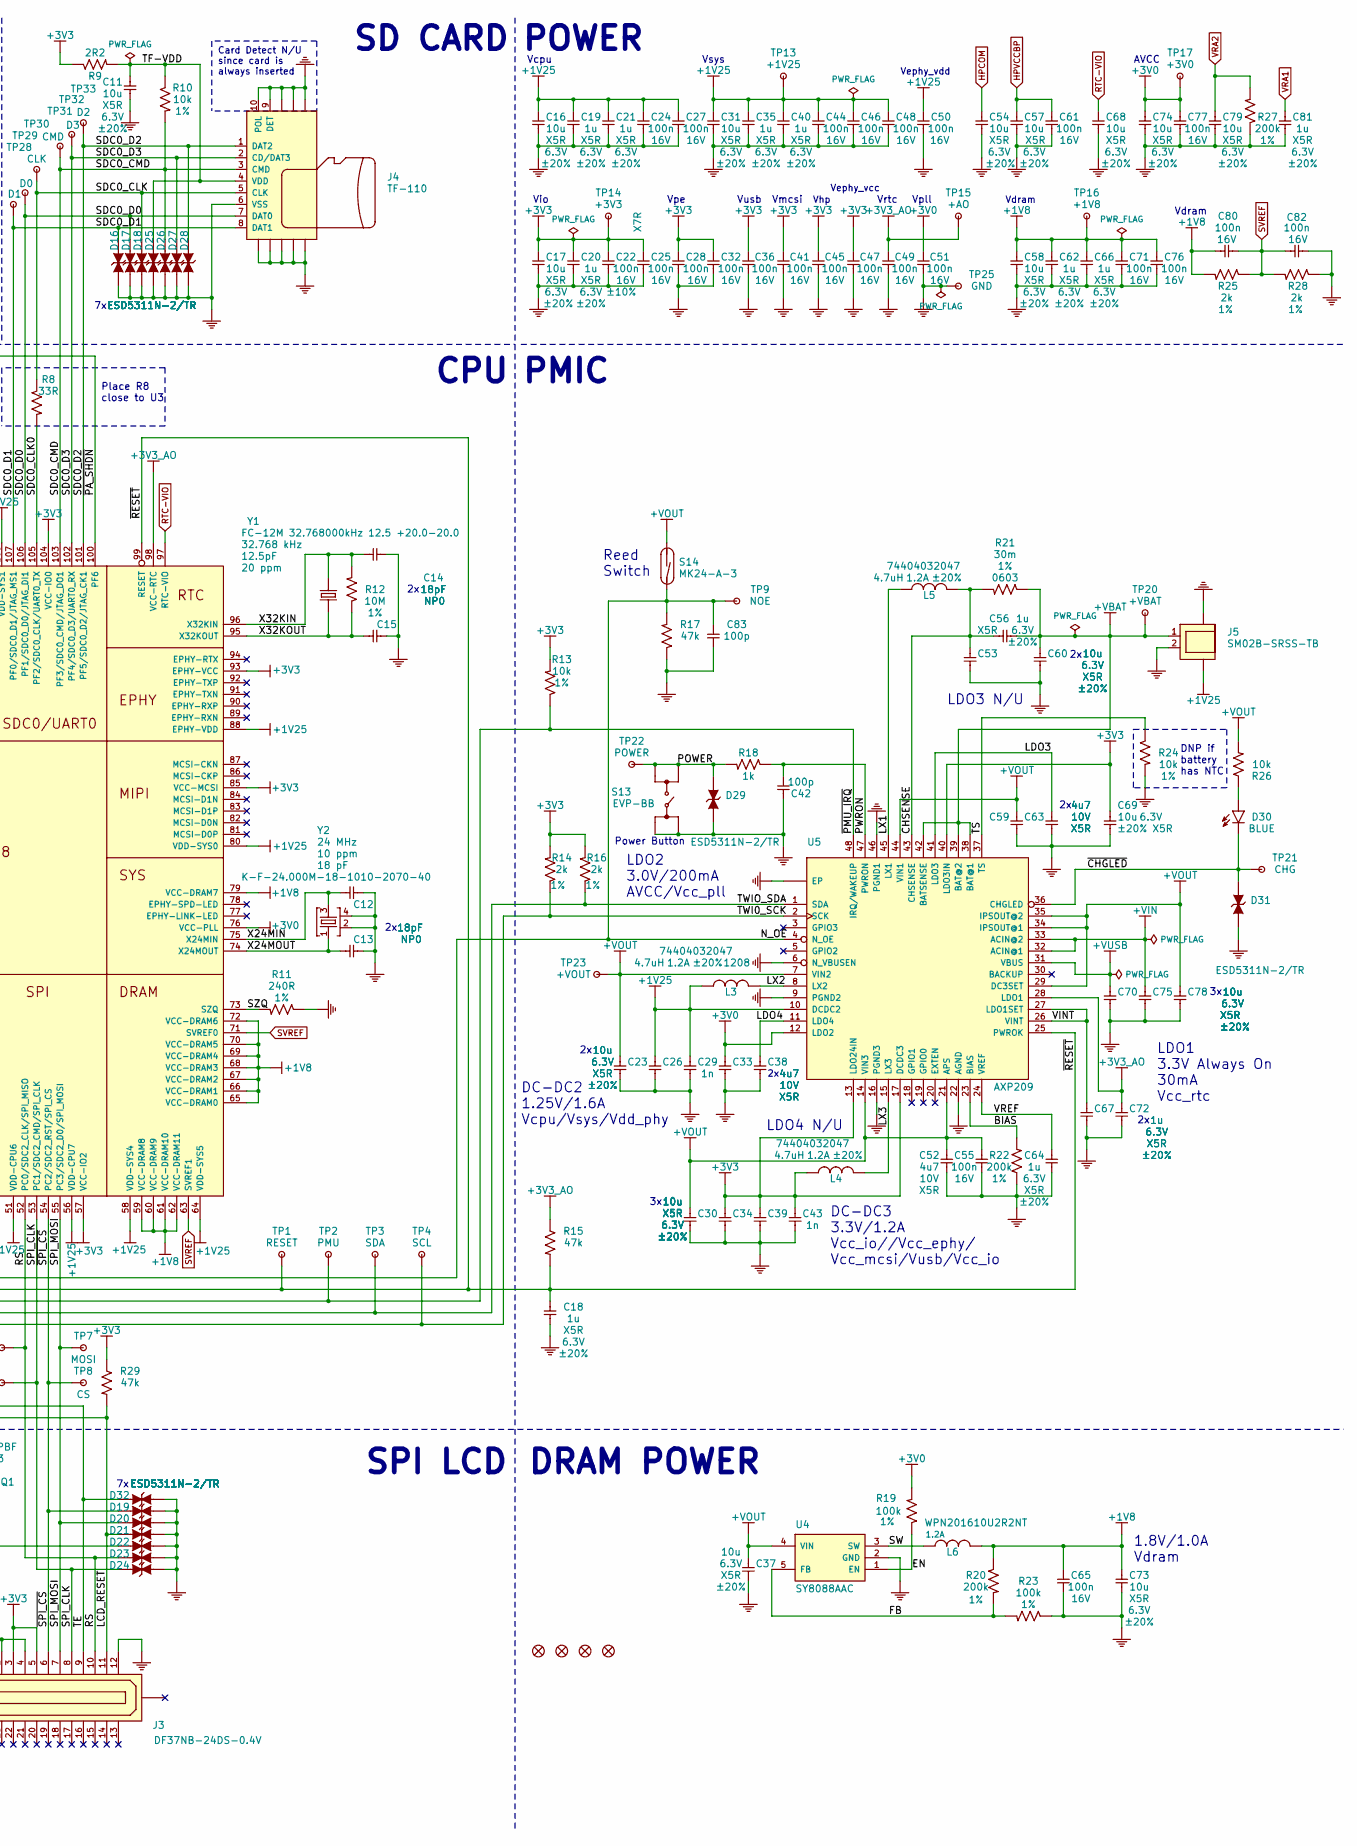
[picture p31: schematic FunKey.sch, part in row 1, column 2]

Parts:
C1, C2, C3, C10, C22, C24, C25, C27, C28, C32, C36, C41, C44, C45, C46, C47, C48, C49, C50, C51, C55, C61, C65, C71, C76, C77, C80, C82: 100n; C0402; PARTNO C0402_100n_X7R_10%_CER_16V
C4, C18, C19, C20, C21, C35, C40, C56, C62, C64, C66, C67, C72, C81: 1u; C0402; PARTNO C0402_1u_X5R_20%_CER_6V3
C5, C8, C11, C16, C17, C23, C26, C30, C31, C34, C37, C39, C53, C54, C57, C58, C60, C68, C69, C70, C73, C74, C75, C78, C79: 10u; C0402; PARTNO C0402_10u_X5R_20%_CER_6V3
C6: 1n; C1206; PARTNO C1206_1n_X7R_10%_CER_500V
C7: 10n; C0402; PARTNO C0402_10n_X7R_10%_CER_50V
C9, C29, C43: 1n; C0402; PARTNO C0402_1n_X7R_10%_CER_50V
C12, C13, C14, C15: 18pF; C0402; PARTNO C0402_18p_NP0_5%_CER_50V
C33, C38, C52, C59, C63: 4u7; C0402; PARTNO C0402_4u7_X5R_10%_CER_10V
C42, C83: 100p; C0402; PARTNO C0402_100p_X7R_10%_CER_50V
D1, D2, D3, D4, D5, D6, D7, D8, D9, D10, D11, D13, D14, D16, D17, D18, D19, D20, D21, D22, D23, D24, D25, D26, D27, D28, D29, D31, D32: ESD5311N-2/TR; ESD0402; PARTNO ESD0402_5V5_BIDIR
D12: ESD5311N-2/TR; ESD0402
D15: PRTR5V0U2X,215; SOT143B; PARTNO PRTR5V0U2X,215
D30: BLUE; LED0402; PARTNO LED0402-BLUE
F1, F2, F3, F4: FIDUCIAL
J1: MH3-1-0.05; PARTNO MH3-1-0.05
J2: U02-BFD3111B0-009; PARTNO U02-BFD3111B0-009
J3: DF37NB-24DS-0.4V; PARTNO DF37NB-24DS-0.4V
J4: TF-110; PARTNO TF-110
J5: SM02B-SRSS-TB; PARTNO SM02B-SRSS-TB
L1: GZ1608D601CTF; FB0603; PARTNO FB0603_600R_25%
L2: CBM321609U601T; FB1206; PARTNO FB1206_600R_25%
L3, L4, L5: 74404032047; WE-LQS; PARTNO 74404032047
L6: WPN201610U2R2NT; L1008; PARTNO L1008
Q1: IRLML2244TRPBF; SOT23-3; PARTNO IRLML2244TRPBF
R1, R10, R13, R24, R26: 10k; R0402; PARTNO R0402_10k_1%_62.5mW
R2, R19, R23: 100k; R0402; PARTNO R0402_100k_1%_62.5mW
R3, R5, R18: 1k; R0402; PARTNO R0402_1k_5%_62.5mW
R4, R15, R17, R29: 47k; R0402; PARTNO R0402_47k_5%_62.5mW
R6, R20, R22, R27: 200k; R0402; PARTNO R0402_200k_1%_62.5mW
R7: 4k7; R0402; PARTNO R0402_4k7_5%_62.5mW
R8: 33R; R0402; PARTNO R0402_33R_5%_62.5mW
R9: 2R2; R0402; PARTNO R0402_2R2_5%_62.5mW
R11: 240R; R0402; PARTNO R0402_240R_1%_62.5mW
R12: 10M; R0402; PARTNO R0402_10M_1%_62.5mW
R14, R16, R25, R28: 2k; R0402; PARTNO R0402_2k_1%_62.5mW
R21: 30m; R0603; PARTNO R0603_30m_1%_333mW
S1, S2: EVP-BB2A9B000; EVP-BB; PARTNO EVP-BB2A9B000
S3, S4, S5, S6, S8, S9, S10, S11: EVP-BB1AAB000; EVP-BB; PARTNO EVP-BB1AAB000
S7, S12: EVP-AE; PARTNO EVP-AE
S13: EVP-BB; PARTNO EVP-BB2A9B000
S14: MK24-A-3; MK24; PARTNO MK24-A-3
SP1: CDM-10008; PARTNO CDM-10008
TP1: RESET; TEST_PAD
TP2: PMU; TEST_PAD
TP3: SDA; TEST_PAD
TP4: SCL; TEST_PAD
TP5: C/D; TEST_PAD
TP6, TP30: CLK; TEST_PAD
TP7: MOSI; TEST_PAD
TP8: CS; TEST_PAD
TP9: NOE; TEST_PAD
TP10: KEY; TEST_PAD
TP11: PA; TEST_PAD
TP12: HP; TEST_PAD
TP13: +1V25; TEST_PAD
TP14: +3V3; TEST_PAD
TP15: +AO; TEST_PAD
TP16: +1V8; TEST_PAD
TP17: +3V0; TEST_PAD
TP18: LCDR; TEST_PAD
TP19: +VUSB; TEST_PAD
TP20: +VBAT; TEST_PAD
TP21: CHG; TEST_PAD
TP22: POWER; TEST_PAD
TP23: +VOUT; TEST_PAD
TP24: LEDA; TEST_PAD
TP25: GND; TEST_PAD
TP26: D-; TEST_PAD
TP27: D+; TEST_PAD
TP28: D1; TEST_PAD
TP29: D0; TEST_PAD
TP31: CMD; TEST_PAD
TP32: D3; TEST_PAD
TP33: D2; TEST_PAD
TP34: TE; TEST_PAD
U1: PCAL6416AHF,128; QFN24; PARTNO PCAL6416AHF,128
U2: PAM8301AAF; TSOT26; PARTNO PAM8301AAF
U3: V3S; ELQFP-128
U4: SY8088AAC; SOT23-5; PARTNO SY8088AAC
U5: AXP209; QFN48; PARTNO AXP209
Y1: FC-12M 32.768000kHz 12.5 +20.0-20.0; FC-12M; PARTNO FC-12M_32K768_12.5PF_20PPM
Y2: K-F-24.000M-18-1010-2070-40; CRYSTAL_32X25; PARTNO XTAL3225_4P_24M_18PF_10PPM

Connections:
+1V8: C58.1, C62.1, C65.2, C66.1, C71.2, C73.2, C76.2, C80.2, L6.2, R20.1, R25.2, TP16.1, U3.59 (VCC-DRAM8), U3.60 (VCC-DRAM9), U3.61 (VCC-DRAM10), U3.62 (VCC-DRAM11), U3.65 (VCC-DRAM0), U3.66 (VCC-DRAM1), U3.67 (VCC-DRAM2), U3.68 (VCC-DRAM3), U3.69 (VCC-DRAM4), U3.70 (VCC-DRAM5), U3.72 (VCC-DRAM6), U3.79 (VCC-DRAM7)
+1V25: C16.1, C19.1, C21.1, C24.2, C26.2, C27.2, C29.2, C31.1, C35.1, C40.1, C44.2, C46.2, C48.2, C50.2, J5.G$2 (G@2), L3.2, TP13.1, U3.19 (VDD-SYS3), U3.20 (VDD-CPU3), U3.21 (VDD-CPU2), U3.25 (VDD-CPU1), U3.26 (VDD-CPU0), U3.38 (VDD-CPU4), U3.47 (VDD-CPU5), U3.51 (VDD-CPU6), U3.56 (VDD-CPU7), U3.58 (VDD-SYS4), U3.64 (VDD-SYS5), U3.80 (VDD-SYS0), U3.88 (EPHY-VDD), U3.108 (VDD-SYS1), U3.126 (VDD-SYS2), U5.10 (DCDC2)
+3V0: C33.2, C51.2, C74.1, C77.2, R6.2, R19.2, TP17.1, U3.76 (VCC-PLL), U3.115 (AVCC), U5.12 (LDO2)
+3V3: C1.2, C2.2, C17.1, C20.1, C22.2, C25.2, C28.2, C32.2, C34.1, C36.2, C39.2, C41.2, C43.2, C45.2, C47.2, C69.1, J3.3, J3.5, L4.1, Q1.2 (S), R1.2, R9.1, R13.2, R14.2, R16.2, R29.1, TP14.1, U1.21 (VDDP), U1.23 (VDD), U3.12 (VCC-PE0), U3.29 (VCC-PE1), U3.50 (VCC-IO3), U3.57 (VCC-IO2), U3.85 (VCC-MCSI), U3.93 (EPHY-VCC), U3.104 (VCC-IO0), U3.109 (VCC-USB), U3.122 (HPVCCIN), U3.127 (VCC-IO1), U5.13 (LDO24IN), U5.17 (DCDC3), U5.40 (LDO3IN)
+3V3_AO: C49.2, C72.1, R15.1, TP15.1, U3.98 (VCC-RTC), U5.28 (LDO1)
+VBAT: C56.2, C60.1, J5.1, R21.1, TP20.1, U5.38 (BAT@1), U5.39 (BAT@2), U5.42 (BATSENSE)
+VIN: C75.1, U5.32 (ACIN@1), U5.33 (ACIN@2)
+VOUT: C23.2, C30.2, C37.2, C52.1, C55.2, C59.1, C78.1, L1.1, R26.2, S14.1 (A), TP23.1, U4.4 (VIN), U5.7 (VIN2), U5.14 (VIN3), U5.21 (APS), U5.29 (DC3SET), U5.34 (IPSOUT@1), U5.35 (IPSOUT@2), U5.44 (VIN1)
+VUSB: C8.2, C10.2, C70.1, L2.2, TP19.1, U5.31 (VBUS)
/A: D3.1, S10.B, S10.B', U1.16 (P1_6)
/B: D2.1, S11.B, S11.B', U1.14 (P1_4)
/BIAS: R22.2, U5.23 (BIAS)
/CHSENSE: C53.1, C56.1, L5.2, R21.2, U5.43 (CHSENSE)
/D: D10.1, S5.B, S5.B', U1.2 (P0_1)
/EN: R19.1, U4.1 (EN)
/FB: R20.2, R23.2, U4.5 (FB)
/FUN: D5.1, S2.B, S2.B', U1.8 (P0_7)
/HPOUTR: C3.1, U3.120 (HPOUTR)
/IN: C3.2, TP12.1, U2.3 (IN)
/L: D9.1, S4.B, S4.B', U1.5 (P0_4)
/LCD_RESET: D21.1, J3.11, R29.2, TP18.1, U3.41 (PB2/UART2_RTS/PB_EINT2)
/LDO3: C63.1, U5.41 (LDO3)
/LDO4: C38.2, U5.11 (LDO4)
/LEDA: D22.1, J3.1, Q1.3 (D), TP24.1
/LRADC0: C9.2, R6.1, U3.112 (LRADC0)
/LX1: L5.1, U5.45 (LX1)
/LX2: L3.1, U5.8 (LX2)
/LX3: L4.2, U5.15 (LX3)
/N_OE: C83.1, R17.2, S14.2 (B), TP9.1, U1.12 (P1_2), U5.4 (N_OE)
/PA_VDD: C4.1, C5.2, L1.2, U2.5 (VDD)
/POWER: D29.1, R18.2, S13.A, S13.A', TP22.1
/PWM: Q1.1 (G), R5.2, R7.1
/PWM0: R5.1, U3.43 (PB4/PWM0/PB_EINT4)
/PWRON: C42.1, R18.1, U5.47 (PWRON)
/R: D11.1, S6.B, S6.B', U1.1 (P0_0)
/RL: D1.1, S12.1 (A), U1.3 (P0_2)
/RR: D12.1, S7.2 (B'), U1.17 (P1_7)
/RS: D23.1, J3.10, TP5.1, U3.52 (PC0/SDC2_CLK/SPI_MISO)
/SDC0_CLK: D18.1, J4.5 (CLK), R8.1, TP30.1
/SDC0_CLK0: R8.2, U3.105 (PF2/SDC0_CLK/UART0_TX)
/SDC0_CMD: D26.1, J4.3 (CMD), R10.2, TP31.1, U3.103 (PF3/SDC0_CMD/JTAG_DO1)
/SDC0_D0: D17.1, J4.7 (DAT0), TP29.1, U3.106 (PF1/SDC0_D0/JTAG_DI1)
/SDC0_D1: D16.1, J4.8 (DAT1), TP28.1, U3.107 (PF0/SDC0_D1/JTAG_MS1)
/SDC0_D2: D28.1, J4.1 (DAT2), TP33.1, U3.101 (PF5/SDC0_D2/JTAG_CK1)
/SDC0_D3: D27.1, J4.2 (CD/DAT3), TP32.1, U3.102 (PF4/SDC0_D3/UART0_RX)
/SPI_CLK: D24.1, J3.8, TP6.1, U3.53 (PC1/SDC2_CMD/SPI_CLK)
/SPI_MOSI: D20.1, J3.7, TP7.1, U3.55 (PC3/SDC2_D0/SPI_MOSI)
/SPK+: D13.1, U2.6 (OUT+)
/SPK-: D14.1, U2.1 (OUT-)
/START: D8.1, S1.B, S1.B', U1.7 (P0_6)
/SW: L6.1, U4.3 (SW)
/SZQ: R11.2, U3.73 (SZQ)
/TE: D32.1, J3.9, TP34.1, U3.40 (PB1/UART2_RX/PB_EINT1)
/TF-VDD: C11.2, D25.1, J4.4 (VDD), R9.2, R10.1
/TS: R24.1, U5.37 (TS)
/TWI0_SCK: R14.1, TP4.1, U1.19 (SCL), U3.45 (PB6/TWI0_SCK/PB_EINT6), U5.2 (SCK)
/TWI0_SDA: R16.1, TP3.1, U1.20 (SDA), U3.46 (PB7/TWI0_SDA/PB_EINT7), U5.1 (SDA)
/U: D6.1, S3.B, S3.B', U1.4 (P0_3)
/UART0_RX: J1.3, U3.49 (PB9/TWI1_SDA/UART0_RX/PB_EINT9)
/UART0_TX: R3.1, U3.48 (PB8/TWI1_SCK/UART0_TX/PB_EINT8)
/UART0_TX0: J1.2, R3.2
/USB_ID: J2.4, R4.1
/USB_N: D15.3, J2.2, TP26.1, U3.110 (USB-DM)
/USB_P: D15.2, J2.3, TP27.1, U3.111 (USB-DP)
/VBUS: C7.1, D15.4, J2.1, L2.1
/VINT: C67.1, U5.26 (VINT), U5.27 (LDO1SET)
/VREF: C64.2, U5.24 (VREF)
/X: D4.1, S9.B, S9.B', U1.15 (P1_5)
/X24MIN: C12.2, U3.75 (X24MIN), Y2.3
/X24MOUT: C13.2, U3.74 (X24MOUT), Y2.1
/X32KIN: C14.2, R12.2, U3.96 (X32KIN), Y1.2
/X32KOUT: C15.2, R12.1, U3.95 (X32KOUT), Y1.1
/Y: D7.1, S8.B, S8.B', U1.13 (P1_3)
/~CHGLED: D30.1 (C), D31.1, TP21.1, U5.36 (CHGLED)
/~KEY_IRQ: R1.1, TP10.1, U1.22 (~INT), U3.42 (PB3/UART2_CTS/PB_EINT3)
/~PA_SHDN: R2.1, TP11.1, U2.4 (~SD), U3.100 (PF6)
/~PMU_IRQ: R13.1, TP2.1, U3.44 (PB5/PWM1/PB_EINT5), U5.48 (IRQ/WAKEUP)
/~RESET: C18.1, R15.2, TP1.1, U1.6 (P0_5), U1.24 (~RESET), U3.99 (RESET), U5.25 (PWROK)
/~SPI_CS: D19.1, J3.6, TP8.1, U3.54 (PC2/SDC2_RST/SPI_CS)
GND: C1.1, C2.1, C4.2, C5.1, C6.2, C7.2, C8.1, C9.1, C10.1, C11.1, C12.1, C13.1, C14.1, C15.1, C16.2, C17.2, C18.2, C19.2, C20.2, C21.2, C22.1, C23.1, C24.1, C25.1, C26.1, C27.1, C28.1, C29.1, C30.1, C31.2, C32.1, C33.1, C34.2, C35.2, C36.1, C37.1, C38.1, C39.1, C40.2, C41.1, C42.2, C43.1, C44.1, C45.1, C46.1, C47.1, C48.1, C49.1, C50.1, C51.1, C52.2, C53.2, C54.2, C55.1, C57.2, C58.2, C59.2, C60.2, C61.1, C62.2, C63.2, C64.1, C65.1, C66.2, C67.2, C68.2, C69.2, C70.2, C71.1, C72.2, C73.1, C74.2, C75.2, C76.1, C77.1, C78.2, C79.2, C81.2, C82.1, C83.2, D1.2, D2.2, D3.2, D4.2, D5.2, D6.2, D7.2, D8.2, D9.2, D10.2, D11.2, D12.2, D13.2, D14.2, D15.1, D16.2, D17.2, D18.2, D19.2, D20.2, D21.2, D22.2, D23.2, D24.2, D25.2, D26.2, D27.2, D28.2, D29.2, D31.2, D32.2, J1.1, J2.5, J3.2, J3.4, J3.12, J4.6 (VSS), J4.9 (DET), J4.10 (POL), J4.G$1 (GND@1), J4.G$2 (GND@2), J4.G$3 (GND@3), J4.G$4 (GND@4), J4.G$5 (GND@5), J4.G$6 (GND@6), J4.G$7 (GND@7), J4.G$8 (GND@8), J5.2, J5.G$1 (G@1), R2.2, R4.2, R7.2, R11.1, R17.1, R22.1, R23.1, R24.2, R27.1, R28.1, S1.A, S1.A', S2.A, S2.A', S3.A, S3.A', S4.A, S4.A', S5.A, S5.A', S6.A, S6.A', S7.1 (A), S7.1' (A'), S8.A, S8.A', S9.A, S9.A', S10.A, S10.A', S11.A, S11.A', S12.2 (B'), S13.B, S13.B', TP25.1, U1.9 (VSS), U1.18 (ADDR), U1.25 (PAD), U2.2 (GND), U3.33 (PE4/CSI_D0/LCD_D2), U3.116 (AGND), U3.GND$1 (EGND), U3.GND$2 (EGND), U3.GND$3 (EGND), U3.GND$4 (EGND), U3.GND$5 (EGND), U3.GND$6 (EGND), U3.GND$7 (EGND), U3.GND$8 (EGND), U3.GND$9 (EGND), U4.2 (GND), U5.6 (N_VBUSEN), U5.9 (PGND2), U5.16 (PGND3), U5.22 (AGND), U5.46 (PGND1), U5.GND$1 (EP), U5.GND$2 (EP), U5.GND$3 (EP), U5.GND$4 (EP), U5.GND$5 (EP), U5.GND$6 (EP), U5.GND$7 (EP), U5.GND$8 (EP), U5.GND$9 (EP), Y2.2, Y2.4
HPCOM: C54.1, U3.124 (HPCOMFB), U3.125 (HPCOM)
HPVCCBP: C57.1, C61.2, U3.123 (HPVCCBP)
unnamed: D30.2 (A), R26.1
PE: C6.1, J2.S$1 (M0), J2.S$2 (M1), J2.S$3 (M2), J2.S$4 (M3)
RTC-VIO: C68.1, U3.97 (RTC-VIO)
SVREF: C80.1, C82.2, R25.1, R28.2, U3.63 (SVREF1), U3.71 (SVREF0)
VRA1: C81.1, U3.117 (VRA1)
VRA2: C79.1, R27.2, U3.118 (VRA2)

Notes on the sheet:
Ceramic capacitors are ±10% 50V X7R dielectric 0402 unless otherwise specified
Resistors are 5% 1/16W 0402 unless otherwise specified
POWER
DNP if battery has NTC
Vusb
Vmcsi
Vrtc
Vpll
Vhp
Vcpu
Vsys
Vio
Vdram
AVCC
SD CARD
AUDIO
DC-DC2 1.25V/1.6A Vcpu/Vsys/Vdd_phy
DC-DC3 3.3V/1.2A Vcc_io//Vcc_ephy/ Vcc_mcsi/Vusb/Vcc_io
LDO4 N/U
LDO3 N/U
LDO1 3.3V Always On 30mA Vcc_rtc
LDO2 3.0V/200mA AVCC/Vcc_pll
1.8V/1.0A Vdram
Place R8 close to U3
Card Detect N/U since card is always inserted
CONSOLE
CPU
DRAM POWER
PMIC
SPI LCD
Power Button
Vpe
Vephy_vcc
Vephy_vdd
BUTTONS
Note: Using U1 internal pull-ups on all buttons
Reed Switch
USB DEVICE
REVISION HISTORY
Rev. A: - Initial version Rev. B: - Correct SZ resistor value - Increase test pad diameter to 1 mm - Drive LCD RESET from a CPU GPIO - Add magnetic Reed switch for cover detection - Change speaker mounting - Solve mechanical interferences Rev. C: - Add test pads for MicroSD and USB - Correct bug (s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

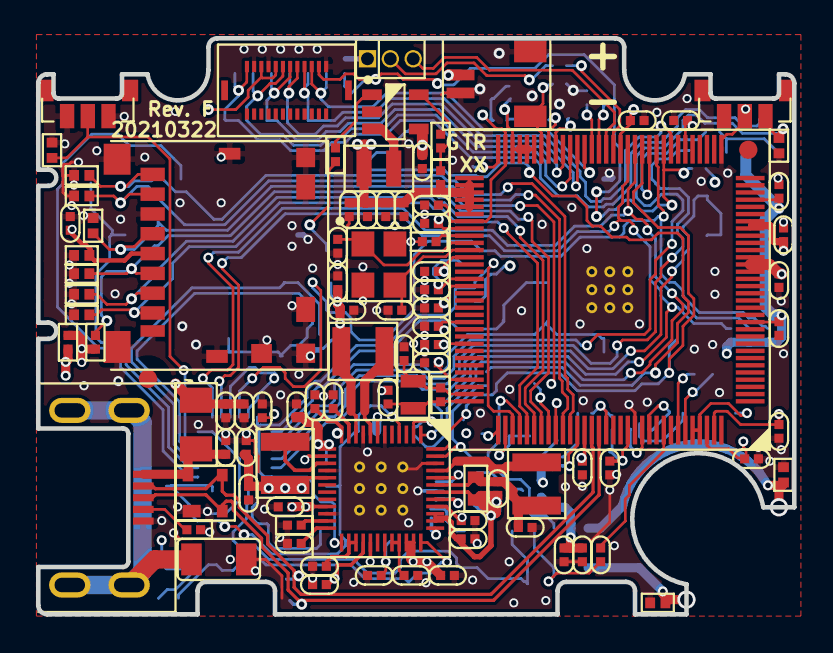
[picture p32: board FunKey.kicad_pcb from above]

Board: 4 copper layers, 42.0 x 32.0 mm, 217 parts (0 on the bottom side), 88 nets.

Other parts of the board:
DRILEGEND: DRILEGEND

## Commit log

2020-11-29 update PCB pictures
2020-11-30 use Protel extensions for gerber files
    [FunKey-B_Mask.gbs, FunKey-B_Paste.gbp, FunKey-B_SilkS.gbo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]
2021-07-27 Revision F with 0.3mm increased length speaker tabs and added drills in the side button corners to make cutout square
    [FunKey-B_Mask.gbs, FunKey-B_Paste.gbp, FunKey-B_SilkS.gbo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]

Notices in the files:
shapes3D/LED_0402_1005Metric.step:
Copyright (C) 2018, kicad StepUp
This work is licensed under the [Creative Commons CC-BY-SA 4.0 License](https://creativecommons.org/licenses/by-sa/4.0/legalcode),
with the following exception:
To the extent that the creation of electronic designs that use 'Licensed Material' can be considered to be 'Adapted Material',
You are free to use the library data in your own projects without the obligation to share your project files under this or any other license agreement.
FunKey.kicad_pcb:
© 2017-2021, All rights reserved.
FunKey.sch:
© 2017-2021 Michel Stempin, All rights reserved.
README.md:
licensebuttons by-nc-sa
